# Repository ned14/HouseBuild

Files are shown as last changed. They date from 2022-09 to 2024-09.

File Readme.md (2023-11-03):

Planning application documents can be found at:

http://planning.corkcoco.ie/PlanningDocumentDisplay/documents/18a-224853

Current VR design can be explored using a web browser at:

https://twinmotion.unrealengine.com/presentation/2OuDxP4Q6LUYExYa
Password: jeuCFyiGwG (model was last updated Oct 11 2022)

Current floor plans:

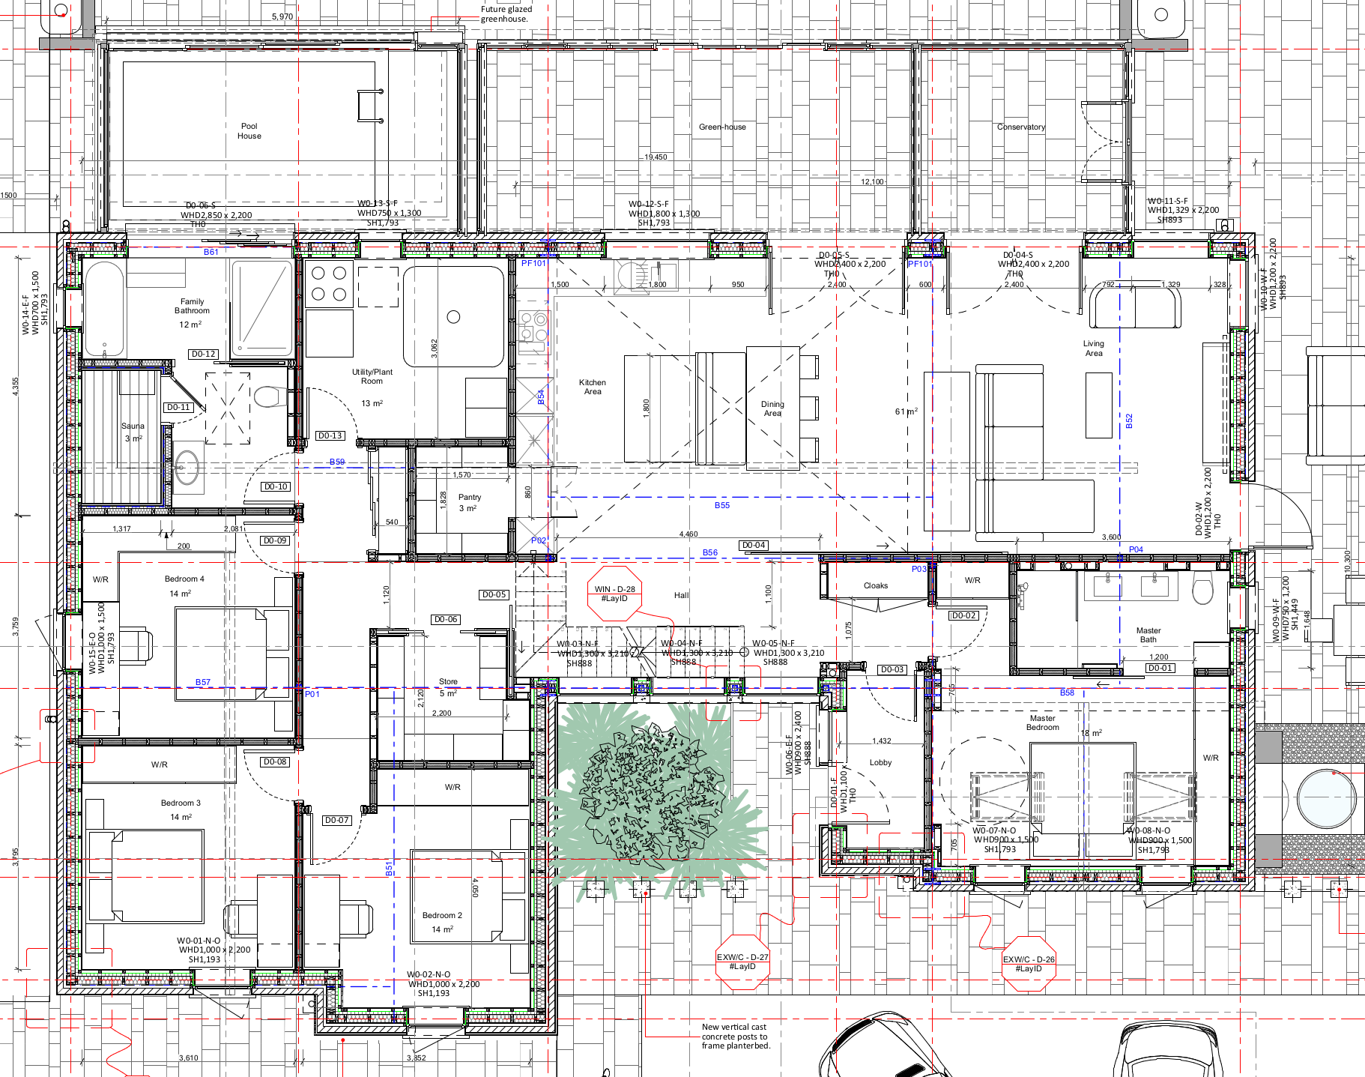
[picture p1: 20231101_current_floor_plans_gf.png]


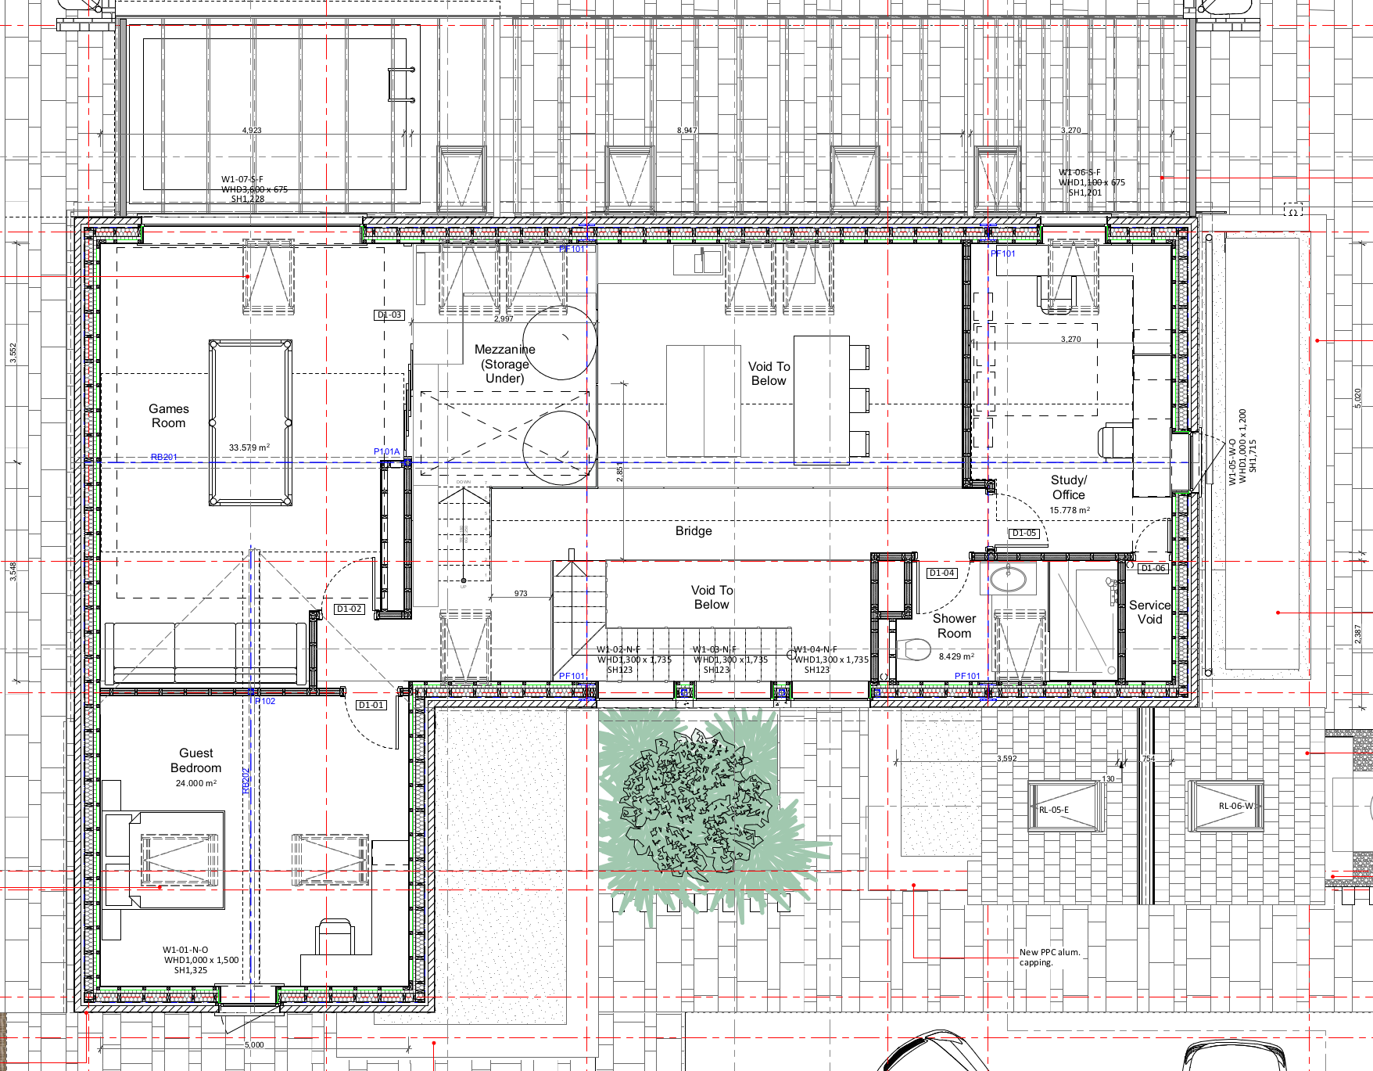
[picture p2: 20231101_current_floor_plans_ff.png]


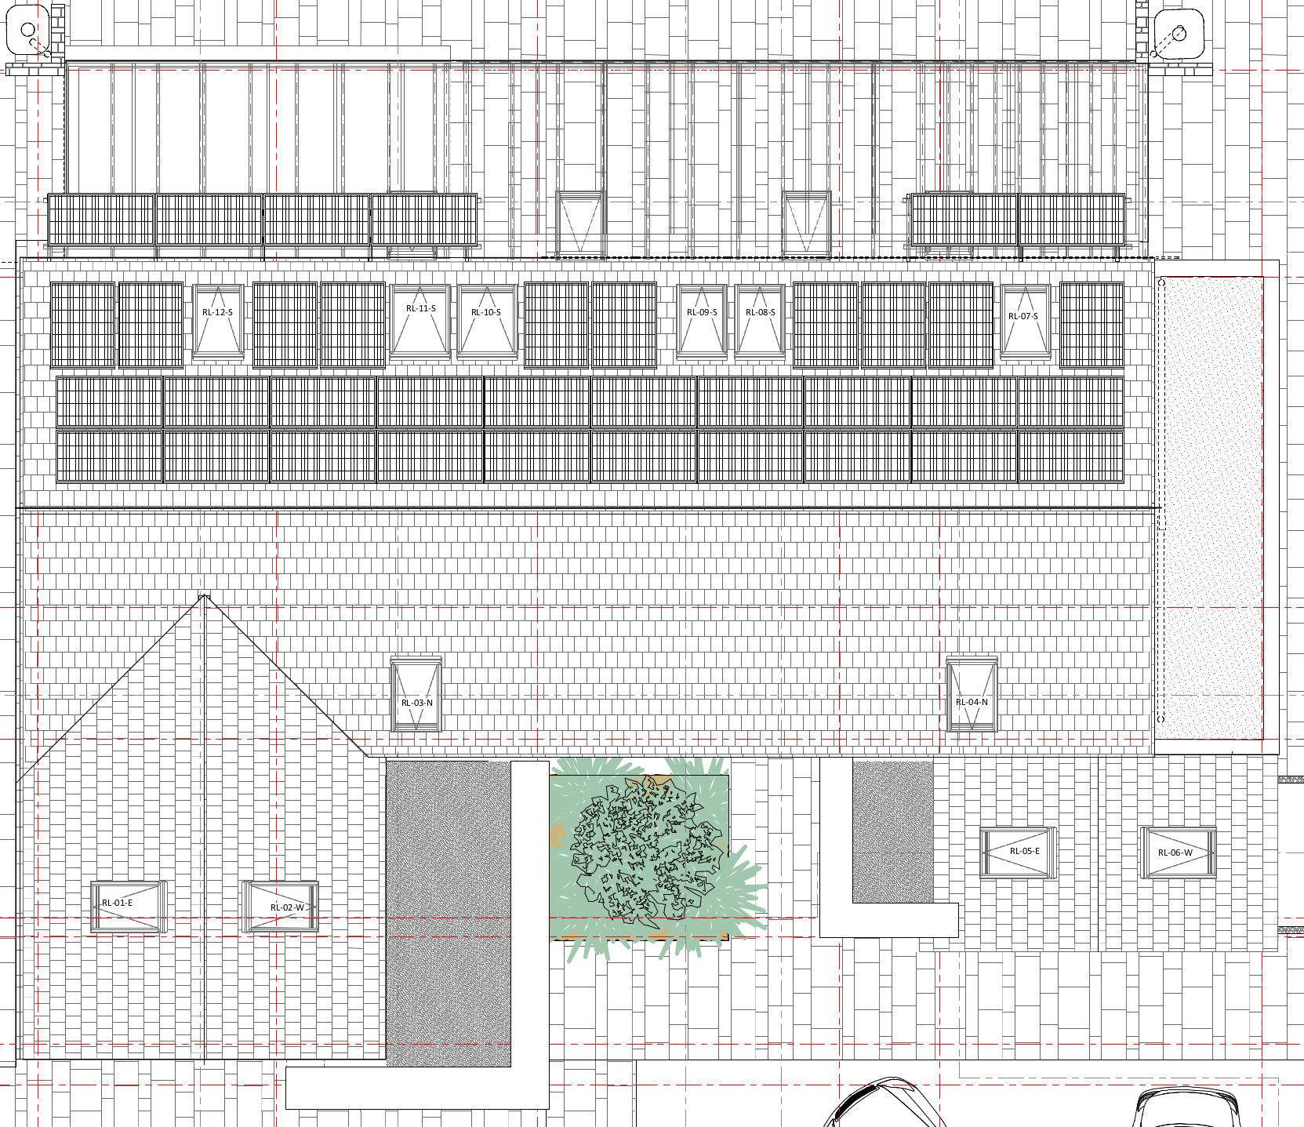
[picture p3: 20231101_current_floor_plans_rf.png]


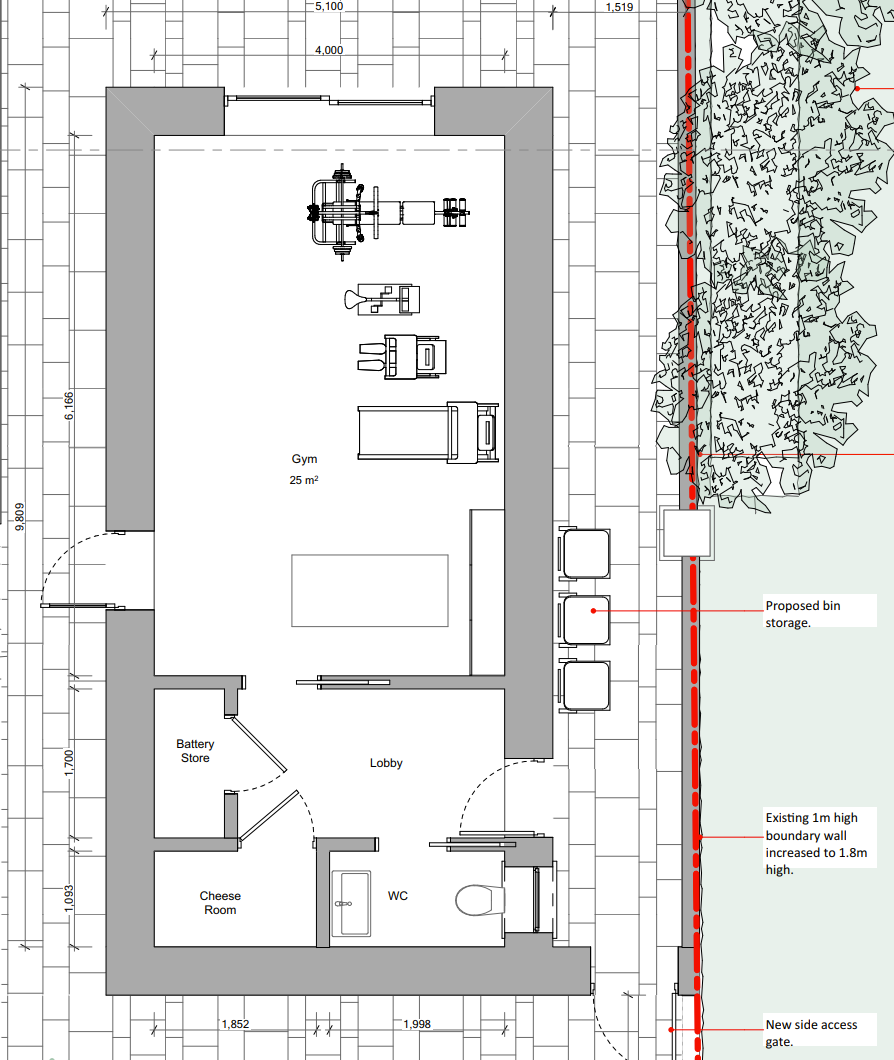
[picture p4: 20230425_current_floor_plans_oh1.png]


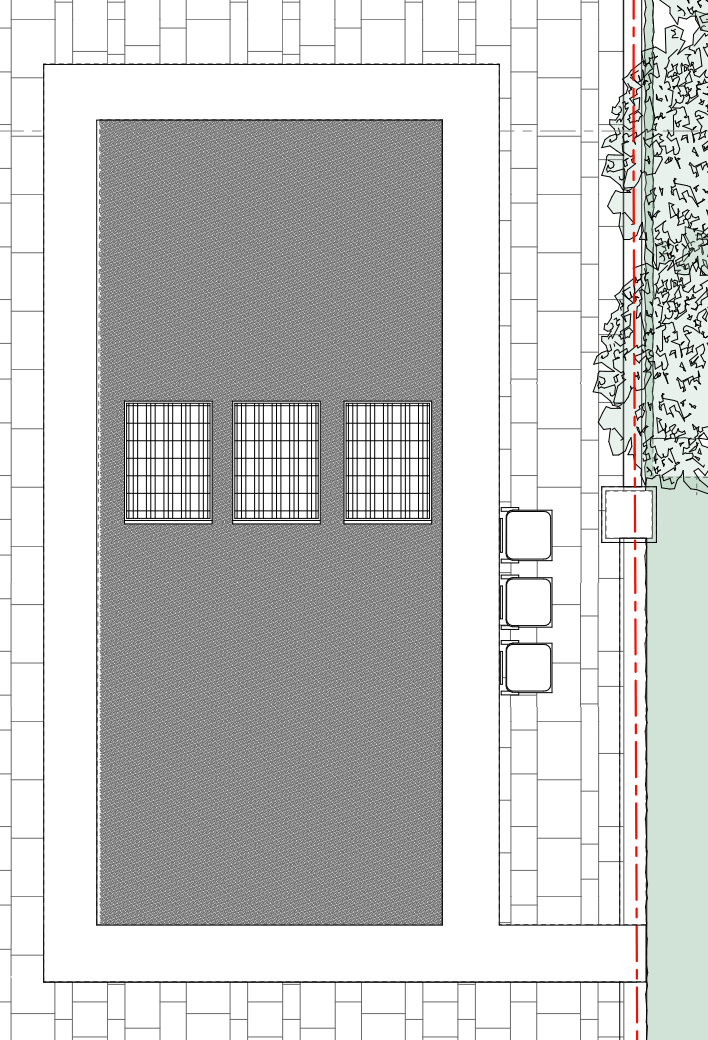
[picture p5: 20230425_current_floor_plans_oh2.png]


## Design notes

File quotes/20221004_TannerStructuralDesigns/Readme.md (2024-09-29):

 Quote is for €10,811.70 inc VAT which includes five site visits.

 PSDP role is further €1,322.25 inc VAT. Each site visit costs €430.50 inc VAT.

 Due to change from builder-led to direct labour, €500 mortgage release fee is replaced with €950 ex VAT fee.

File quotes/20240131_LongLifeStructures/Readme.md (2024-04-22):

# Quote

Main house: €375,382 inc VAT to first fix. This is €1,294 inc VAT per sqm.
    - Timber frame _excluding insulation_ is €229,137 inc VAT. This is €769 inc VAT per sqm.
    - Air tightness and exterior insulation is €63,002 inc VAT.
    - Foundations is €64,322 inc VAT for the house, €18,921 inc VAT for the greenhouse minus pool,
    €20,541 inc VAT for the pool part alone (ouch!).

Outhouse: not quoted

# Includes:

- Main house to first fix.
- All needed _exterior_ insulation.
- Interior partition studs, but not the insulation within them.
- Groundworks (except clearance, hardcore compacted and level by client)
- Floors: 0.10; Walls: 0.134; Roof (sloped): 0.15; Roof (flat): 0.09. Floor is typical KORE insulated slab, 0.10.
- **Guaranteed air tightness < 0.6 ACH to meet passive spec**

# Excludes:

- Structural Engineering (+10k cost)
- Prepatatory groundworks (hard core and services poke up) (+20k cost)
- Roof slates and flat roof (EPDM) (+29k cost)
- Plasterboard (+53k cost)
- Insulation inside internal walls
- External windows and doors (+50k cost)
- Excludes installing roof windows
- Wiring (+10k cost)
- Plumbing (+4k cost)
- External block leaf (plastered) (+53k cost assuming 333 m2 of exterior wall at €160 per sqm plastered)
- External footpaths (+26k cost)
- Glass Ballustarding (+16k cost)
- Stairs (+5k cost)
- Internal doors (+12k cost including skirting and window sills)
- Rubbish removal
- Site costs such as scaffolding, welfare cabin for workers, waste disposal etc.

That is €288k of cost remaining, so total to reach Builder's Finish would be €656k.

If I wanted to add sheep's wool to the inner cavity of the sloped roof to reduce its u-value to 0.13, it might cost:

- Sloped roof area: 9.5 + 11.0 + 21.7 + 21.7 + 54.0 + 43.6 = 161.5 m2
- Assuming 400 centres, reduce by 12% = 144 m2 of insulation needed
- https://www.ecologicalbuildingsystems.com/product/cosywool#product-overview says €7.55 ex VAT per m2, 22 kg/m3, R = 0.039
- So approx +€1,250 inc VAT to add sheep's wool for sloped roof

- Fireproof, denser alternatives:
    - €8.85-€10.24 inc VAT per m2, 35 kg/m3 50 mm https://www.goodwins.ie/products/rockwool-sound-slab-50mm-1-2x400mm-5-76m2-1252120.html. €1,274 inc VAT, almost the same but 59% denser and fireproof. R I think might be 0.035?

For internal wall insulation, which needs more density than anything else:

- €20.23 inc VAT per m2, 37 kg/m3 100 mm https://www.ecologicalbuildingsystems.com/product/thermo-hemp-combi-jute
- €16.82-€19.44 inc VAT per m2, 35 kg/m3 100 mm https://www.goodwins.ie/products/rockwool-sound-slab-100mm-1-2x400mm-2-88m2-1252127.html
- €16.57-€18.75 inc VAT per m2, 35 kg/m3 100 mm https://www.goodwins.ie/products/rockwool-sound-slab-100mm-1-2x600mm-4-32m2-1252128.html
- €15.27 inc VAT per m2, 22 kg/m3 100 mm Rockwool Rollbatt
- €16.84 inc VAT per m2, 12 kg/m3 100 mm Isover Acoustic roll

- Rockwool Flexi (predecessor to Sound Slab) is £14.58 inc VAT per m2 in England, which seems similar to Irish prices.
- Rockwool RWA45 is €23.60 per m2 in Ireland, yet only £8.58 inc VAT in England. It is 45 kg/m3. https://buildersinsulation.co.uk/products/100mm---rockwool-rwa45-acoustic-sound-insulation-slab---2.88m2-pack.html
- Rockwool RW3 is £13.54 inc VAT in England. It is 60 kg/m3.

Just to make a person really wince:

- £27.43 https://www.muffle.co.uk/rockwool-rwa45-acoustic-slab-insulation-100mm-2-88m2-pack-of-4.html
- €68.25 https://ie.muffleacoustics.com/rockwool-rwa45-acoustic-slab-insulation-100mm-2-88m2-pack-of-4.html

# Payment terms:

- €25k incl VAT deposit.
- €83k for the foundations completed (minus pool).
- 40%: Prepayment of offsite manufacture (€92k)
- 40%: Prepayment of install (€92k)
- Balance: Engineering sign for frame (€45k)
- €56k for the airtightness.

€230k needs to go out in near future.

# Other notes:
- The split stud EcoTech Homes quote was for €472,108 inc VAT to first fix. Differences to this quote:

    - Walls: 0.13; Roof (sloped): 0.16; Roof (flat): 0.11

    - Includes roof slates and flat roof EPDM (29k)
    - Includes more of the groundworks (maybe worth 18k)
    - Includes all plasterboard (maybe €53k though that includes labour)
    - Includes installing roof windows
    - Includes insulation for internal walls (5k?).

    Taking those off, that quote would reduce to €367k, literally the same as the split stud EcoTech quote on a like for like basis.

- The single stud EcoTech Homes quote was for €361,297 inc VAT to first fix. Differences to this quote:

    - Walls: 0.16; Roof (sloped): 0.16; Roof (flat): 0.11.

    - Includes roof slates and flat roof EPDM (29k)
    - Includes more of the groundworks (maybe worth 18k)
    - Includes all plasterboard (maybe €53k though that includes labour)
    - Includes installing roof windows
    - Includes insulation for internal walls (5k?).

    Taking those off, that quote would reduce to €256k. So the above quote is 111k more than the single stud EcoTech quote on a like for like basis.

- Closest competing quote for a similar spec is TimberFrameIreland. This is from last year for a 300 mm split stud:

    Main house: €218,328 inc VAT to first fix (€92,620 + €38,030 "The Eco Package" which is the 300 mm split stud + €2,690 + €6,740 + €860 + €51,420). This is €732 inc VAT per sqm.

    - Excludes air tightness taping (14k probably)
    - Excludes air blower test
    - **Question:** Is roof truss and flat roof insulation included by TimberFrameIreland? If not, potentially 20k there.

    - Walls have 0.11 u-value instead of 0.13. Roof (sloped) has 0.11 u-value instead of 0.13.

    Assuming same cost of air tightness and insulation minus walls (so maybe +35k), that would be 253k inc VAT. The above quote is 71.9% more money for 18% worse u-values.

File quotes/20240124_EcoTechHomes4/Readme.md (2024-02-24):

# Quote

Main house: €472,108 inc VAT to first fix. This is €1,584 inc VAT per sqm.

Outhouse: not quoted

# Includes:

- Main house to first fix.
- Roof slates
- Flat roof (EPDM), insulation partially fitted.
- Plasterboard, **but not fitted**
- Groundworks (except clearance, hardcore compacted and level by client)
- Floors: 0.10; Walls: 0.13; Roof (sloped, excludes insulated plasterboard): 0.16; Roof (flat): 0.11. Floor is typical KORE insulated slab.
- **Guaranteed air tightness < 0.6 ACH to meet passive spec**

# Excludes:

- **Insulated floor for greenhouse**
- Structural Engineering (+10k cost)
- External windows and doors (+50k cost)
- Wiring (+10k cost)
- Plumbing (+4k cost)
- External block leaf (plastered) (+53k cost assuming 333 m2 of exterior wall at €160 per sqm plastered)
- External footpaths (+26k cost)
- Glass Ballustarding (+16k cost)
- Stairs (+5k cost)
- Internal doors (+12k cost including skirting and window sills)
- Rubbish removal
- Site costs such as scaffolding, welfare cabin for workers, waste disposal etc.

# Payment terms:

-  6.5%: Initial deposit
- 18.0%: Prepayment of foundations
- 16.5%: Prepayment of offsite manufacture
- 42.0%: Prepayment of install
- 14.0%: Prepayment of roof slates
-  3.0%: After completion

# Other notes:
- This differs from the earlier quote as it is for a 300 mm split stud with posi-joists, rather than 220 mm with normal joists. The price for the earlier spec was €361,297 inc VAT. This, obviously enough, is €110,811 more.
- Estimated cost to Builder's Finish: €684k inc VAT.
- Closest competing quote is TimberFrameIreland. This is from last year, but for the same 300 mm split stud:

    Main house: €218,328 inc VAT to first fix (€92,620 + €38,030 "The Eco Package" which is the 300 mm split stud + €2,690 + €6,740 + €860 + €51,420). This is €732 inc VAT per sqm.

    - Excludes roof slates and flat roof EPDM (29k)
    - Excludes more of the groundworks (maybe worth 18k)
    - Excludes internal wall insulation
    - Excludes all plasterboard (maybe €53k though that includes labour)
    - Excludes installing roof windows
    - Excludes air blower test
    - **Question:** Is roof truss and flat roof insulation included?

    - Walls have 0.11 u-value instead of 0.13. Roof (sloped) has 0.11 u-value (includes plasterboard) instead of 0.16 (excludes plasterboard).

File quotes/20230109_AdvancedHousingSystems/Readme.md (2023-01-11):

# Quote

Main house: €643,699 inc VAT to second fix (€545,040 superstructure; €98,659 substructure). This is €2,083 inc VAT per sqm.

Outhouse: not quoted

# Includes:

- Main house to second fix.
- Insulated floor for greenhouse
- **Structural Engineering**
- **M&E engineering**
- Floors: 0.10; Walls: 0.10; Roof: 0.10.
- Internal walls: 100mm quilt wool insulation.
- **Guaranteed air tightness < 0.6 ACH to meet passive spec**

# Excludes:

- Everything between second fix and builder's finish (e.g. wiring, plumbing, door frames, skirting boards)
    - +10k cost electrical, +4k cost plumbing
- External block leaf (plastered) (+53k cost assuming 333 m2 of exterior wall at €160 per sqm plastered)
- External footpaths (+26k cost)
- Roof slates (+25k cost)
- Glass Ballustarding (+16k cost)
- Stairs (+5k cost)
- Internal doors (+12k cost including skirting and window sills)
- Rubbish removal
- Site costs such as scaffolding, welfare cabin for workers, waste disposal etc.

# Payment terms:

- 12%: Initial deposit
- 12%: Design completion
- 22%: Prepayment of offsite manufacture
- 9%: Prepayment of windows and doors
- 20%: Offsite manufacture completed
- 10%: Arrival of team onsite
- 4%: Delivery of windows and doors
- 8%: Completion of superstructure ground floor
- 3%: Completion of superstructure build

# Other notes:

- The cash flow crunch is going to be particularly problematic here, because the bank's mortgage drawdown stages don't map onto their stages. I reckon I would need to front about half the total build cost which would need to be completed before the bank would let me drawdown. That is a problem.
- Once accounting for structural and M&E engineering, this is a touch (13k!) cheaper than the Ecotech quote.
    - I filled in the items which the Ecotech quote includes, but we'd need to supply with this contractor, from the Quantity surveyor's estimates. It thinks those items would sum to €151k. On that basis, this quote ought to be €795k.
- The spec of this house is way higher than the Ecotech quote. Vastly superior u-values for one, I suspect build quality would be better too, so the +21% cost is likely competitive for the spec delivered. However €138k is an awful lot of money which can be used to buy other stuff instead.

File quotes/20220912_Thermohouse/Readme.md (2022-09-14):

# Quote

Main house: €226,213 inc VAT to passive spec wall insulation < 0.15 u-value. This is €732 inc VAT per sqm.

Outhouse: €40k inc VAT (note that they omitted the insulated floor)

# Includes:

- Substructure and **Outer** Superstructure, no Windows nor Doors, no Foundations, no Ground Floor, no Services.
- First floor.

# Excludes:

- Structural Engineering
- Excavation and backfilling
- Foundations
- **Ground floor**
- Window cills
- Stairs
- **Most of the internal walls**
- Roof tiles, fascia and soffet
- **Outer leaf**
- Site costs such as scaffolding, welfare cabin for workers, waste disposal etc.
- **Any form of air tightness testing or guarantees related to air leakage**
- The steel frame for the glazing at the front of the house.

# Payment terms:

- 20% deposit
- Stage payments at ground floor, floor panels, first floor, steel and finally the roof panels

# Other notes:

- If combined with outer block leaf, they claim it falls under 'standard construction' and I suppose given it's then similar to insulated block on flat it probably does tick that box.
- To reach passive air tightness with ICF one generally must spray all the inside of the building enveloper with a rubberised layer to seal all the tiny gaps. As with any new building, foundations will shift over time and tears can appear in that rubberised layer, requiring a second spray a decade in or so.
- Obviously all that concrete, polystyrene and steel is absolutely hideous for the embodied CO2, though not much between this and the average NZEB spec Irish new build to be honest.

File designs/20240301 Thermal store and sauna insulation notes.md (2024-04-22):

## U-values

- 0.639 30mm thick  30mm Kingspan Sauna Satu
- 0.616 45mm thick  15mm plasterboard + 30mm Kingspan Sauna Satu
- 0.592 50mm thick  mineral wool
- 0.341 75mm thick  15mm plasterboard + 30mm Kingspan Sauna Satu + 30mm Kingspan Sauna Satu
- 0.283 68mm thick  37.5mm Kingspan K118 insulated plasterboard  + 30mm Kingspan Sauna Satu
- 0.238 80mm thick  50mm Kingspan K108 phenolic board + 30mm Kingspan Sauna Satu
- 0.186 103mm thick 72.5mm Kingspam K118 insulated plasterboard  + 30mm Kingspan Sauna Satu
- 0.181 105mm thick 75mm Kingspan K108 phenolic board + 30mm Kingspan Sauna Satu

Apparently Kingspan phenolic board is happy with continuous 120 C, and they originally make it by baking it at over 200 C. I'm not entirely sure why they use PIR for saunas not phenolic, as supposedly phenolic is moisture safe as well.

Thermal store is 1.7 x 1.7 x 2.91 = 19.8 m2 sides + 5.8 m2 top bottom = 25.5 m2 all surfaces.

BUT one side is exterior wall at 0.15 u-value, so 5 m2 get 0.11 u-value, 20.5 m2 gets rest. So 20% gets 0.15 u-value, 80% gets rest.

If inside is 85 C and outside is 20 C then 65 K difference => 1332.5 m2K for interior, 325 m2K for exterior.

If inside is 55 C and outside is 20 C then 35 K difference => 717.5 m2K for interior, 175 m2K for exterior.

In reality, bottom will not be as warm at top, so leakage will be better than these:

### Winter:

- 0.639 u-value => 851 + 36 = 887 watts leakage worst case
- 0.283 u-value => 377 + 36 = 413 watts leakage worst case
- 0.181 u-value => 241 + 36 = 277 watts leakage worst case

### Summer:

- 0.639 u-value => 458 + 19 = 477 watts leakage worst case
- 0.283 u-value => 203 + 19 = 222 watts leakage worst case
- 0.181 u-value => 130 + 19 = 149 watts leakage worst case

I know from https://core.ac.uk/download/pdf/13724924.pdf that for a 1.7 m tall tank insulated with 50mm of mineral wool, heat stratification will result in a max 14 C temp difference. If there is any churn at all, more like 11 C. That is approximately 13-14 cm per degree of temp difference.

For a 2.8m tall tank, the temp difference could be 20 - 22 C, for 50 mm of mineral wool. 50 mm of mineral wool has 0.592 u-value.

Let's assume better insulation has a linear effect on stratification. Temp delta to outside would
be average of top and bottom temps, so if there is a 21 C top-bottom difference, a 65 K delta
becomes 65 - (21 / 2) = 54.5.

### Winter:

- 0.639 u-value =>  21 C temp diff => 83.8% = 743 watts after stratification
- 0.283 u-value =>  10 C temp diff => 92.3% = 381 watts after stratification
- 0.181 u-value => 6.4 C temp diff => 95% = 263 watts after stratification

### Summer:

As only top quarter heated, assume tank is one third normal height and thus loses one
third of worst case.

- 0.639 u-value => 159 watts
- 0.283 u-value => 74 watts
- 0.181 u-value => 50 watts

## Wood

Alder and Aspen are the only two woods one should use in a sauna. Not cedar.

Spruce is cheaper, but can emit resin which will burn you and is sticky.

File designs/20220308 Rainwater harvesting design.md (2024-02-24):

# Rainwater harvesting design

(These notes were reconstituted from many emails around that time)

Model soakaway crate used is 1000 x 1000 x 400 mm deep and requires 500 mm of soil above it.

- https://www.drainagesuperstore.co.uk/product/aquacrate-stormwater-soakaway-and-attenuation-crate-20-tonne-25-per-m3.html
- https://www.drainagesuperstore.co.uk/user-guides-brochures/aqua-crate-400-data-sheet.html

Top of the lower reed bed tray to be 74.25. Top of the 0.4m deep soakaway to be 74.19, with a 6 cm fall between them. Each reed bed tray is 0.2m fall.

Footpath north of house is 74.60. Channel drain south of footpath 74.50 (slope 1% from house footpath). Footpath east of outhouse is 74.60. Top of first reed bed tray is 74.47 (slope 0.5% from channel drain next to outhouse). Top of second reed bed tray is 74.25 (0.22m drop). Top of underground storage tank is 74.24.

For underground storage to overflow into stormwater mains, top of stormwater drain has to be no higher than 73.99 (1% slope over 15 metres). Footpath is 74.36, and min thickness according to regs is 225 mm. Assuming 250 mm, top of stormwater drain will be no higher than 74.11 and as a 110mm diameter pipe, its bottom would be 74.00.

---

(These are written now, in Jan 2024)

I can't explain, looking at it now, why I thought a 0.2m fall is needed _per tray_. As far as I can tell now, It is a _once off_ 0.2m fall into the 0.8m deep tray, because the inlet pipe comes in below the top of the tray. The Kingspan trays take a 110 mm inlet pipe, the Herr trays seem to take a 50 mm inlet pipe. After your once off 0.2m drop from the top, the trays can all be equal height as static pressure will ensure each tray gets the same height of water -- indeed, they could be connected by a bottom pipe for water level equalisation, and the outlet water drawn off the top.

That might explain some of the more confusing parts of the above where I did the measurement of the outlet from the top of the second tray. I must have also been thinking in at top, between trays at bottom, out at top.

The Kingspan tray is 2.5m long, 0.8m wide and 0.8m deep. Not sure what the dimensions of the Herr tray is.

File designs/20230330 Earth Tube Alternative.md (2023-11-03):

Given that quotes for the Rehau Awadukt Thermo delivered to Ireland are
coming in over €7k ex VAT, what alternatives are there?

# Option 1: Water pipes

The Rehau pipes are just very high quality polypropylene 200 mm mains
water pipes with a specially sprayed inner of silver oxide. One
could just source bog standard 200 mm mains water pipes instead.
https://www.mcmahons.ie/200mm-pvc-watermain-pipe-class-c-x-6m
lists 200 mm 10 bar capable PVC watermains pipes 6m length for
€80.89 ex VAT each. This seems suspiciously cheap? They also have a
250mm diameter edition. These probably refer to outside diameter,
not DN diameter which is the inside.

225 mm 6m length PVC sewer pipes cost €137 ex VAT each. 

You can buy from https://www.amazon.de/Stainless-Steel-Suction-Tower-Filters/dp/B07DHQHV6H?ref_=ast_sto_dp
the air inlet tower with five spare filters for under €600 inc VAT
delivered for DN200, or https://www.amazon.de/Stainless-Steel-Suction-Tower-Filters/dp/B07DHQYPCH?ref_=ast_sto_dp
for DN250 for under €700 inc VAT delivered.

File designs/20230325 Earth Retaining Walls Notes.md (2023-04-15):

Worst case weight loading is:

     - Blocks are 1.4m long 0.68 wide 0.7 tall. Exactly 0.6666667 m<sup>3</sup>.
     - 7.5 blocks long three blocks high = 10.5m x 0.68 = 7.14 m<sup>2</sup> of area
     - 7.5 blocks long three blocks high = 31,500 kg

Therefore worst case weight loading is 4,412 kg per m<sup>2</sup>.

Safe bearing capacity of soils:

    - Medium clay: 25,000 kg per m<sup>2</sup>.
    - Packed fine sand: 15,000 kg per m<sup>2</sup>.
    - Loose fine sand: 10,000 kg per m<sup>2</sup>.
    - Soft clay: 10,000 kg per m<sup>2</sup>.
    - Very soft clay: 5,000 kg per m<sup>2</sup>.

Should be no problem there.

Normal solid concrete blocks have a density of 2,000 kg/m<sup>3</sup>.
These have 2,100 kg/m<sup>3</sup>.

Therefore footing probably ought to be at least 150 mm deep and 1.0m wide.

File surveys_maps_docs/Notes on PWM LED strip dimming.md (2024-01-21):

The house exterior and site will be mainly illuminated by RGBWW LED strips which each have a five pin connector:

1. Common anode +24v
2. Red
3. Green
4. Blue
5. Warm white (3200K)

## Exterior

The exterior LED strips have already been purchased:

- 50x 5m IP67 Tube Waterproof 24v SMD 5050, 60 LEDs/metre
    - To be used edges of house fascia, edges of site.
    - Listing claimed max 12w/metre and 350-450 mcd/LED. Likely 20% worse.
    - Probably max 72w 3.0 amp on the anode.
    
- 4x 5m 1P67 Tube Waterproof 24v **double row** SMD 5050, 120 LEDs/metre
    - To be used where more brightness is needed e.g. western wall outhouse passage, inside of shipping container
    - Listing claimed 16w/metre and 18-20 lumen/LED. Empirical testing found 20w/metre (listing was 20% under this), and 2,200 lumen/metre from subjective sight seems generous.
    - Max 100w 4.2 amp on the anode, may be able to get more brightness if both ends are wired in as the common anode will limit max current. Strictly speaking only the +24v common anode needs wiring in at both ends.

## Interior

- 5x 5m 3500K CRI95 LED strip 11w/metre.

    - 3x for roof of living area above TV.
    - 1x for end of hallway.
    - 1x for back of games room.

All likely using the recessed LED channels below.

- 1x 5m 4000K CRI95 waterproof LED strip 28.8w/metre.

    - Upstairs bathroom where we needed an ultra bright
strip to uplight. Had wanted 3500K but couldn't get
that in waterproof. Couldn't get 3000K either, only 2800K,
so ended up going for 4000K which is disappointing but water
under the bridge now.

- 1x 5m 3000K CRI95 ultra bright LED strip 38.4w/metre.

    - Top of stairs around grandfather clock. This is beyond
ultra bright, more like insanely bright. Idea here is to uplight
from below so it will be reflecting back down.

- 1x 5m 3000K RA90 RGBWW COB LED strip.

    - Sauna.

- 2x 5m 3700K COB LED strip 15w/metre.

    - Additional lighting around both ground floor showers.
Not waterproof, but it'll be inside recessed channels and
it's COB so it should be fine.

- 1x 5m 4000K RA95 COB LED strip 10w/metre.

    - Ground floor bathroom mirrors MISSING STRIP FOR ONE
MAYBE TWO.

- 24x 3000K CRI90 MR16 bulb 120 degree 7w.

    - Accidentally got ten too many. Anywhere needing a
wide cosy throw where people are standing e.g. hallways,
utility, bathrooms.

    - These were very cheap (under €1 delivered), and appear to
have no heatsink at all. They get hot quickly at full power,
and will need PWM dimming to get much lifespan from them. They are
marked 'Gatetop' but that's the Aliexpress shop front name, most
of the MR16 bulbs on Aliexpress are likely from the same manufacturer.

- 8x 3000K CRI90 MR16 bulb 38 degree 7w.

    - Mainly bedrooms, the warmest colour we use.

    - These were very cheap (under €1 delivered), and appear to
have no heatsink at all. They get hot quickly at full power,
and will need PWM dimming to get much lifespan from them. They are
marked 'Gatetop' but that's the Aliexpress shop front name, most
of the MR16 bulbs on Aliexpress are likely from the same manufacturer.

- 15x 3500K CRI90 MR16 bulb 40 degree 8w.

    - Living spaces where high CRI matters.

    - These are called "expensive Satco" below. They were about US$12
each. They dim very smoothly over a large range, have clearly superior
heatsinking, and their power regulator doesn't care about input voltage
which suggests a fully switched power converter. These are clearly the
best bulbs I bought on all measured metrics, but at 15x the cost of
the very cheap Aliexpress ones I'd wonder if there is cost benefit.

- 12x 3500K CRI80 MR16 bulb 40 degree 6w.

    - Living spaces where lower CRI can be tolerated.

    - These are called "cheap Satco" below. They were about US$9
each, three quarters the price of the expensive Satco. They have at least
some heatsinking compared to the very cheap Chinese bulbs resulting
in temperatures a few degrees lower, but otherwise seem very similar
i.e. they get hot fast, and may even have an inferior driver IC to those
very cheap bulbs (see below).

- 16x 4000K CRI90 MR16 bulb 38 degree 7w.

    - Anywhere needing focus and concentration i.e. kitchen
countertops, home office.

    - These were very cheap (under €1 delivered), and appear to
have no heatsink at all. They get hot quickly at full power,
and will need PWM dimming to get much lifespan from them. They are
marked 'Gatetop' but that's the Aliexpress shop front name, most
of the MR16 bulbs on Aliexpress are likely from the same manufacturer.

- 24x fixed 3cm recessed downlight fixtures.

    - Hallways, kitchen countertops.

- 36x tiltable 3cm recessed downlight fixtures.

    - Everywhere else.

- 27x 0.5m recessed aluminium LED strip channel for 8mm wide tape.

- 30x 0.5m recessed aluminium LED strip channel for 12mm wide tape.

- 10x 0.5m double sided aluminium LED strip coving.

- 10x 0.5m brushed black skirting channel for LED strip.

- 10x 0.5m brushed rose gold skirting channel for LED strip.

- 10x 6 amp two pole DC circuit breakers.

- 10x 6 amp one pole DC circuit breakers.

- 28x 12 AWG mini car fuse leads.

- 25x 8 kHz DC PWM wall dimmer switches.

    - Verified with oscilloscope these genuinely do run an 8 kHz
PWM. They're actually configurable between 500 Hz, 1 kHz, 2 kHz,
4 kHz and 8 kHz. This turns out to be super useful when paired
with the MR16 bulbs, which expect clipped AC to tell them when
to dim.

- 2x 4 Khz DC PWM wall dimmer switches.

    - Bought in case the 8 kHz switches didn't work out as samples.
Turns out the 8 kHz switches work great.

- 4x touchpanel RGBW wall dimmer switches.

    - Only need one, but bought spares as they were very cheap
and I don't trust the touch interface at all to be reliable.

## PWM dimming

### MOSFET choices

For some reason, the 5v "logic level" IRLxxx MOSFETs don't seem to come on convenient breakout breadboards, only the 10v IRFxxx MOSFETs do (note the 'L' vs 'F' difference). This is unfortunate, however what I really would want is 3.3v MOSFETs so I can skip the logic level shifter which is added cost and wiring (that said, what max frequency an affordable 3.3v MOSFET could switch at I don't know).

The two choices of MOSFET on convenient breakout boards and which are cheap are chinese clones of the IRF520N and IRF540N, both 10v saturating devices. Both allow a reasonable current for a 5v saturation, albeit considerably less than the maximum current they are capable of. I guess this is why "they'll do" for most makers.

I have a bunch of single channel IRF520N boards from my initial round of purchasing in 2021, and one of those powers the experimental LED strip cover lighting in the living room of my rented house. It works pretty well, albeit the MOSFET does run hot i.e. wastes energy.

To see if I could improve on this, I bought 10x cheap four channel IRF540N MOSFET boards to test if that single integrated board would be feasible and save me hassle wiring up individual MOSFETs. These are optically isolated apart from ground, and have a LED wired inline to the MOSFET input which roughly lops half a volt off the signal voltage. They present a common anode, and switch the cathode only which is perfect for the LED strips. The optocoupler chip (PS2801-4) limits the output voltage to 9 - 80v, as it is powered by the output voltage.

Assuming that the chinese clone MOSFETs have these characteristics:

<table>
<thead><th><th>IRF520N<th>IRF540N
<tbody>
<td align="right">R<sub>DS</sub><td>0.20<td>0.052
<td align="right">R<sub>thJA</sub><td>62<td>62
<td align="right">Max I<sub>D</sub> for<br>V<sub>GS</sub> @ 4.5v<td>2.5 A<td>20 A
<td align="right">Max I<sub>D</sub> for<br>V<sub>GS</sub> @ 5.0v<td>4 A<td>32 A
<td align="right">Max I<sub>D</sub> for<br>V<sub>GS</sub> @ 10v<td>9.7 A<td>33 A
</tbody>
</table>

Heating in watts = Current ^ 2 * R<sub>DS</sub>

Resulting temperature increase over ambient = Heating watts * R<sub>thJA</sub>

Where R<sub>DS</sub> is for a control voltage of 10v and the MOSFET's temperature is 20 C:

<table>
<thead><th>Current<th>IRF520N watts<th>IRF520N temp<th>IRF540N watts<th>IRF540N temp
<tbody>
<td>0.63 A<td>0.08 W<td>+5.0 C<td>0.02 W<td>+1.3 C
<td>1.00 A<td>0.20 W<td>+12 C<td>0.05 W<td>+3.2 C
<td>2.00 A<td>0.80 W<td>+50 C<td>0.2 W<td>+13 C
<td>2.50 A<td>1.25 W<td>+78 C<br>(needs cooling)<td>0.33 W<td>+20 C
<td>4.00 A<td>3.20 W<td>+198 C<br>(needs cooling)<td>0.82 W<td>+52 C
</tbody>
</table>

One would multiply watts and temp heating by 1.5 if the temperature were 100 C, so clearly the IRF520N runs away with waste heat past 2.0 A or so. One probably ought to also increase the heating to account for a control voltage of 4.5v vs 10v.

I have a IRF520N on the living room LED strip which I think draws about 2.2 A, and it gets really quite hot even with its heatsink. With hindsight it was the wrong choice of MOSFET for such a high current, but at the time I didn't know any better.

In any case, I reckon the four channel IRF540N boards should waste no more than 0.4 W of heat from the four MOSFETs if the LED strip is fully on for the 120 LEDs/metre strips, and 0.16 W for the 60 LEDs/metre strips. Given that each ESP32 board and its associated 60v to 24v converter will waste single digit watts, I don't think the losses from the MOSFETs will matter (and they won't need heatsinking either).

### MOSFET control option 1: Use direct PWM

The industrial ESP32 boards can PWM dim up to twelve channels, so theoretically up to three 5m LED strips can be controlled per board. In practice, most use cases will have an ESP32 board per two LED strips, as the other GPIO will be used for I2C sensors etc.

Probably a 14,648Hz PWM will be used, which gives 4,096 steps per RGBW channel. You need to make sure when introducing logic level shifters or optoisolaters etc that they are capable of switching at at least that frequency. Any bog standard FET based level shifter should be capable of 100 Khz, if you need more then a buffered level shifter such as the TXS0108E should be good up for 2 - 60 Mhz which should be enough to level shift even a SPI connection.

As inferred here, you will need a level shifter with this option, because the FET needs a 5v control signal to saturate. Whilst inexpensive, the level shifter boards each need soldering and wiring in with two sets of power and control signals and this is hassle. If one has other 5v peripherals, this might be okay, but to be honest it's rare I'd choose a peripheral without 3.3v control support, even if it a 5v powered device.

### MOSFET control option 2: Use a PCA9685 LED driver

These cost under €3 inc VAT delivered and provide sixteen i2c controlled PWM channels with 4,096 steps per channel. They can output 5v whilst being controlled by 3.3v, which saves on level shifters. ESPHome treats them as if ESP32 PWM outputs, so integration is seamless and you can of course daisy chain them as they are i2c devices. The only bad thing about them is that they probably still need soldering (though all the Aliexpress photos show them presoldered), and their maximum PWM clock is 1,526Hz which is unfortunately low (flicker).

### MOSFET control option 3: Use a TLC5947 LED driver

These cost under €7 inc VAT delivered and provide twenty-four SPI controlled PWM channels with 4,096 steps per channel. They can output up to 30v at 30mA, and work just fine with 3.3v control. They have a 4Mhz clock, which is surely sufficient, and can be daisy chained on SPI.

In case you're thinking we could have them drive a higher voltage than 5v into the MOSFETs to save heat wastage, yes you can. But we only have available 24v or 5v, and the MOSFETs won't take more than 20v into their input without burning out.

As with all the other options, these also need soldering, but the fact you can run eight LED strips from each board and with good quality dimming is attractive.

### MOSFET control option 4: Use a 24v PWM dimming rotary wall switch

This is the most expensive option, costing €17.20 inc VAT delivered each. Though it also saves on the cost of a wall switch, its single most attractive feature is saving me time. This is actually the one I ended up choosing, despite its expense, as my time is so very limited. I can later upgrade lighting control with ESP32 as needed.

The unit I bought claimed it could work with 12v (the listing claimed 5v) to 24v at up to 6 amps, with 180 watts specified as maximum (that doesn't make sense to me either). It claims to support five output frequencies: (i) 500 Hz (ii) 1000 Hz (iii) 2000 Hz (iv) 4000 Hz (v) 8000 Hz. This will be useful for working with MR16 bulbs, that expect an AC dimming signal. I couldn't tell from the Aliexpress description if they meant dimming levels, or PWM frequency (later I used an oscilloscope to check, and they did mean PWM frequency, these switches do use a 8000 Hz PWM frequency when so configured).

Having received them and cracked one open, they are based on two 60N03 MOSFETs. The MOSFETs can cope with up to 30v and their control signal is TTL, and the datasheet reckons they can push up to 320 watts. There is a TM1651 LED driver control IC, but it is for the eight segment number display only. An unmarked IC appears to do all the real work. A 78L05 voltage regulator takes in 0 - 30v and outputs 5v, its datasheet says it needs a minimum 7.5v to produce 5v. With 5v input it produces 3.5v, which is above TTL so a lot of ICs should still work. All the ICs with identifiers I could see their datasheets all say they're happy at 3.3v, so only the unmarked IC will be the question. I ended up putting it onto my variable voltage power supply, it appears (just about) happy at 5.0v albeit with the numbers display rather dim, but 4.8v is too little and it hangs. The numbers display appears to reach full brightness at around 8v, so I suspect its needs 5v from that voltage regulator for full brightness but is happy down to TTL.

After empirical testing, I have found:

- The very cheap Chinese MR16 bulbs have no issue being put into series, which to be honest was rather the surprise. Each claims 10v for itself minimum, one of the other bulbs takes the balance, it all 'just works'.
- The Satco bulbs don't like being put into series at all. One goes out, the other gets full voltage.

The dimmer switch PWMs the cathode, so you get a series of pulses connecting to ground. Unfortunately the MOSFET boards above are anode switched, with a pull up resistor you can invert the dimming setting, but that's hardly ideal.

I could install special 54v => 12v converters throughout the house and put the Satco bulbs in parallel, however I already have lots of 54v => 24v converters in stock and they're more efficient in any case. It seemed above that the Satco bulbs don't mind 24v input:

- The AMC7105 MR16 driver IC will accept between 4.0v and 40v.
- The iW3662 MR16 driver IC will accept between 10.0v and 24v.
- The MAX16840 MR16 driver IC will accept between 5.6v and 46v.
- The MAX31840 MR16 driver IC will accept between 6.5v and 26v.
- The TPS92560 MR16 driver IC will accept between 6.5v and 42v.

These seem to be the most common MR16 LED driver ICs, and they all accept 24v.

**Unfortunately** from thermal camera testing of the very cheap Chinese MR16 bulbs it would seem the higher the input voltage, the much more heat gets output which means bulb lifetime will be impacted, so using 24v throughout for those is probably unwise. Whatever IC they use it appears to treat 10v as 100% brightness, and it performs a dim down to about 4v -- anything above 10v appears as increased heat dissipation (even 12v), so they might even have a linear regulator in there to save costs. I saw a max temp of 60 C on 10v with it going to 72 C on 12v, it went to 80 C before I pulled the plug on 24v. Unfortunate.

For the cheap Satco, it was a similar story to very cheap Chinese bulbs: more voltage equals more heat, but the heatsinking is slightly better. The 24v bulb went to 90 C within a few minutes, the 12v bulb got to 58 C. Dimming is smooth between 3.6v and 10v, I couldn't see brightness change 10v to 12v.

For the expensive Satco, they are completely idempotent to input voltage. On both 12v and 24v they reach 46 C and stay there. Identical. They turn on quite brightly at 3.6v which is the lowest my variable power supply can go, and have a smooth dim from there right up to 12v which appears to mean 100% for them. In PWM dimming testing these bulbs had by far the widest dimming range, going from just above off smoothly to full brightness. I very much like the colour of the light from the bulbs, they're generally just lovely. I guess you get what you pay for, and the cheap Satco are actually lousy value for money considering they're barely better than the 'Gatetop' Aliexpress bulbs at one tenth their price.

I guess what all this means is I'm going to need a bunch more ~60v DC to 10v DC converters (more likely it'll be 12v). Let's hope the January sales have hefty discounts.

For sizing:

- Very cheap Chinese use ~0.44 amps at 12v. As you drop the voltage below 10v, amps also drops with voltage as they dim. They claim to be a 7w bulb, that clearly is usual Aliexpress 'listing claims 25% over reality' at 5.3w at most.
- Cheap Satco use ~0.56 amps at 12v. As you drop the voltage to 8v they will ramp up amps to 1 amp, after which they dim whilst holding current constant. They claim to be a 6.5w bulb, however they actually consume as much as 8w and run at 6.72w normally. These really are poor bulbs, consuming up to 8w when their box claims 6.5v is unacceptable.
- Expensive Satco use ~0.60 amps at 12v. As you drop the voltage to 10.6v they will ramp up amps to 0.73 amp, after which they dim whilst holding current constant. They claim to be an 8w bulb, however they never exceed 7.7w and run at 7.2w normally.
- I didn't mention it above as I only have a couple of them so not worth the testing time: a 'Goodlite' 3500K 7w MR16 bulb uses 0.61 amps at 12v, which is 7.3w. These are different again, as you drop the voltage they keep ramping current upwards to compensate, with an apparent constant current cap at 1.15 amps, after which they dim.

So tl;dr; you need to budget one amp per bulb worst case if they're connected in parallel. So five bulbs could draw 5 amps of 12v.

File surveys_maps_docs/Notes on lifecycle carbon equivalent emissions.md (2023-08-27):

## Goal

- RIBA 2030 climate challenge of < 625 kg of embodied CO<sub>2e</sub> per m<sup>2</sup>
and < 35 kWh of operational energy per m<sup>2</sup> per year.
    - House has 312 m<sup>2</sup>, so this is 195 metric tonnes of embodied
    carbon and 10,920 kWh of operational energy per year.
    - RIBA uses a 60 year lifespan (the EU uses a 50 year lifespan).
- RIAI's target is < 450 kg of embodied CO<sub>2e</sub> per m<sup>2</sup>.
    - This is 140.4 metric tonnes for my house.

## Estimates for my house

Note https://epdireland.lca-data.com/processList.xhtml?stock=PUBLIC lists EPDs
publicly available for building components in Ireland. I note nothing there
on timber frames nor prefabricated floors.

https://www.igbc.ie/generic-data/ supplies estimates for some of the missing
common items.

- Timber seems to be -616 to -681 kg of embodied CO<sub>2e</sub>
per m<sup>3</sup>. God knows how many metres cubed of timber a timber framed
house might use, I assume it isn't a huge amount per m<sup>2</sup>. 
- CEM I (portland cement) is 763 kg of embodied CO<sub>2e</sub> per metric tonne.
- CEM III (used in readymix) is 371-512 kg of embodied CO<sub>2e</sub> per metric tonne.
- Solid concrete blocks appear to be 10.6 kg of embodied CO<sub>2e</sub>
per m<sup>2</sup>. A m<sup>2</sup> of concrete block weighs 142.5 kg, therefore
that is 74.4 kg of embodied CO<sub>2e</sub> per metric tonne.
- Steel girders is 1,490 kg of embodied CO<sub>2e</sub> per metric tonne.

You can get more detailed EPDs (yet to do):

- Sodra of Sweden supply the structural timber, mainly from Sweden and Finland.
- Roof trusses and/or rafters from Sodra or Balcas.
- Loose rafters from Glennon Bros mills.
- OSB by Coillte, Irish sourced timber.
- Plasterboard is from Gyproc, Irish manufacturer though surely the gypsum is
from abroad.

### Installation

- 114.2 metric tonnes for shell and foundations (366 kg CO<sub>2e</sub>
per m<sup>2</sup>, a non-PH NZEB house might be 267 kg CO<sub>2e</sub>
per m<sup>2</sup>, perhaps the +37% is a bit much, equally triple glazed
windows plus thicker insulation embodies lots more carbon).
- 2 metric tonnes for the lithium batteries.
- 2.5 metric tonnes for the hybrid inverter.
- 12.2 metric tonnes for the solar panels.
- ? for the steel girders pinning the insides together.
- ? for the thermal store.
- ? for heavy lorry transport of all the above.

Already above is 130.9 metric tonnes, this is close to the 140.4 limit.

Avoided:

- 1.5 metric tonnes by avoiding heat pump.

### During use

- 10 metric tonnes as lithium batteries would need replacing five times in sixty years.
- 5 metric tonnes as the hybrid inverter would need replacing two times in sixty years.
- 24.4 metric tonnes as the solar panels would need replacing twice in sixty years.
- ? metric tonnes as the windows would need replacing once in sixty years.

Avoided:

- Any refrigerant leakage from heat pumps or replacement thereof.

This definitely exceeds the RIAI challenge of < 450 kg of embodied
CO<sub>2e</sub> per m<sup>2</sup> as 170.3 metric tonnes is already
consumed (this is 545 kg of embodied CO<sub>2e</sub> per m<sup>2</sup>).

#### Operational carbon

- Annual operational energy use per year: 9360 kWh (30 kWh per m<sup>2</sup> per year)
    - Annual grid contribution: 2572 kWh
    - Annual grid demand: 2299 kWh

After offsetting winter by summer, mildly reduces overall CO<sub>2e</sub>
emitted by 106.2 kg per year. This is 6.4 metric tonnes over sixty years.

During winter, it is generally windier, plus we recharge the thermal
store and lithium batteries using cheap night rate electricity which
tends to mostly come from wind farms by definition, so we might in
practice do better than that amount of carbon saved.

## Assumptions

- Irish/UK housing (for a sample 200 m<sup>2</sup> house probably meeting
pre-2019 regs as house was in the UK) has a total lifecycle of:
    - A1-A3 Materials:
        - Masonry: 304 kg CO<sub>2e</sub> per m<sup>2</sup>.
        - Timber Frame: 179.9 kg CO<sub>2e</sub> per m<sup>2</sup>.
    - A4 Transportation:
        - Masonry: 4.3 kg CO<sub>2e</sub> per m<sup>2</sup>.
        - Timber Frame: 1.7 kg CO<sub>2e</sub> per m<sup>2</sup>.
    - A5 Construction:
        - Masonry: 39.2 kg CO<sub>2e</sub> per m<sup>2</sup>.
        - Timber Frame: 37.7 kg CO<sub>2e</sub> per m<sup>2</sup>.
    - B1-B5 Maintenance and Replacement:
        - Masonry: 18.4 kg CO<sub>2e</sub> per m<sup>2</sup>.
        - Timber Frame: 13.2 kg CO<sub>2e</sub> per m<sup>2</sup>.
    - B6 Energy:
        - Masonry: 376.5 kg CO<sub>2e</sub> per m<sup>2</sup>.
        - Timber Frame: 386.6 kg CO<sub>2e</sub> per m<sup>2</sup>.
    - B7 Water:
        - Masonry: 11.9 kg CO<sub>2e</sub> per m<sup>2</sup>.
        - Timber Frame: 11.1 kg CO<sub>2e</sub> per m<sup>2</sup>.
    - C1-C4 End of life:
        - Masonry: 26.9 kg CO<sub>2e</sub> per m<sup>2</sup>.
        - Timber Frame: 23.8 kg CO<sub>2e</sub> per m<sup>2</sup>.

- A certified passive house in Passive House Plus got 575 kg CO<sub>2e</sub> per
m<sup>2</sup> excluding PV modules, inverter etc.
    - Windows, doors and roof lights: 95 kg CO<sub>2e</sub> per
m<sup>2</sup>.
        - Windows and doors alone: 39 kg CO<sub>2e</sub> per
m<sup>2</sup> to install, 29 kg CO<sub>2e</sub> per
m<sup>2</sup> during use, 39 kg CO<sub>2e</sub> per
m<sup>2</sup> to dispose at end of life.
    - Substructure: 109 kg CO<sub>2e</sub> per m<sup>2</sup>.
    - Superstructure incl wood and insulation: 162 kg CO<sub>2e</sub> per m<sup>2</sup>.
    - MVHR + HP (three replacements): 119 kg CO<sub>2e</sub> per m<sup>2</sup>
    (24 to install, 94 during use, 1 to dispose at end of life).

- Lithium batteries a total lifecycle of 150-200 kg CO<sub>2e</sub> per kWh of capacity
 (source: https://www.energimyndigheten.se/globalassets/forskning--innovation/transporter/c243-the-life-cycle-energy-consumption-and-co2-emissions-from-lithium-ion-batteries-.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). This probably assumed a ten year lifespan.
    - Perhaps 73 kg CO<sub>2e</sub> per kWh of capacity to manufacture.
    - Note BYD Battery Box are cobalt free, and Lithium Ion Phosphate chemistry.
    - Ours is a 10.24 kWh system weighing 167 kg.
    - It has 96% efficiency.
    - BYD guarantee at least 60% of capacity will remain after ten years OR
    30.82 MWh of power has been supplied by a 10.24 kWh system (this is 3,010
    cycles).

- A Huawei 6kW hybrid inverter had a total lifecycle CO<sub>2e</sub> of 1504 kg,
 23% of which was production, 76% was use (through energy wasted by heat over its
 25 year assumed lifespan), and a fairly unbelievably low < 1% went on end of life
 (source: https://www.ske-solar.com/wp-content/uploads/2021/01/Zertifikat-Product-Carbon-Footprint-Report-f%C3%BCr-Huawei-SUN2000-6KTL-L1-Wechselrichter.pdf).
    - Our Sungrow unit is 10kW which would cost a bit more materials in production,
    but the batteries means only very rarely does its waste heat come from the grid.

- Solar panels have a total lifecycle CO<sub>2e</sub> of 615 kg per kW. Another
source says 242 kg CO<sub>2e</sub> per m<sup>2</sup>.

- A 6kW heat pump has a total lifecycle of 220-260 kg CO<sub>2e</sub> per kW of
capacity. A 40kW heat pump has a total lifecycle of around 130 kg CO<sub>2e</sub>
per kW of capacity. Lifespan was assumed to be fifteen years. Source: https://www.cibsejournal.com/technical/embodied-energy-the-whole-picture/

- In 2022 the Irish electrical grid emitted 0.389 kg of CO<sub>2e</sub> per kWh
generated. This is not delivered however, apparently the Irish electrical grid
had transmission losses of 8% in 2022. This gives 0.42 kg of CO<sub>2e</sub> per
kWh delivered.

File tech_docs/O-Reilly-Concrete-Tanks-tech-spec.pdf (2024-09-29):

# Precast Concrete Tanks

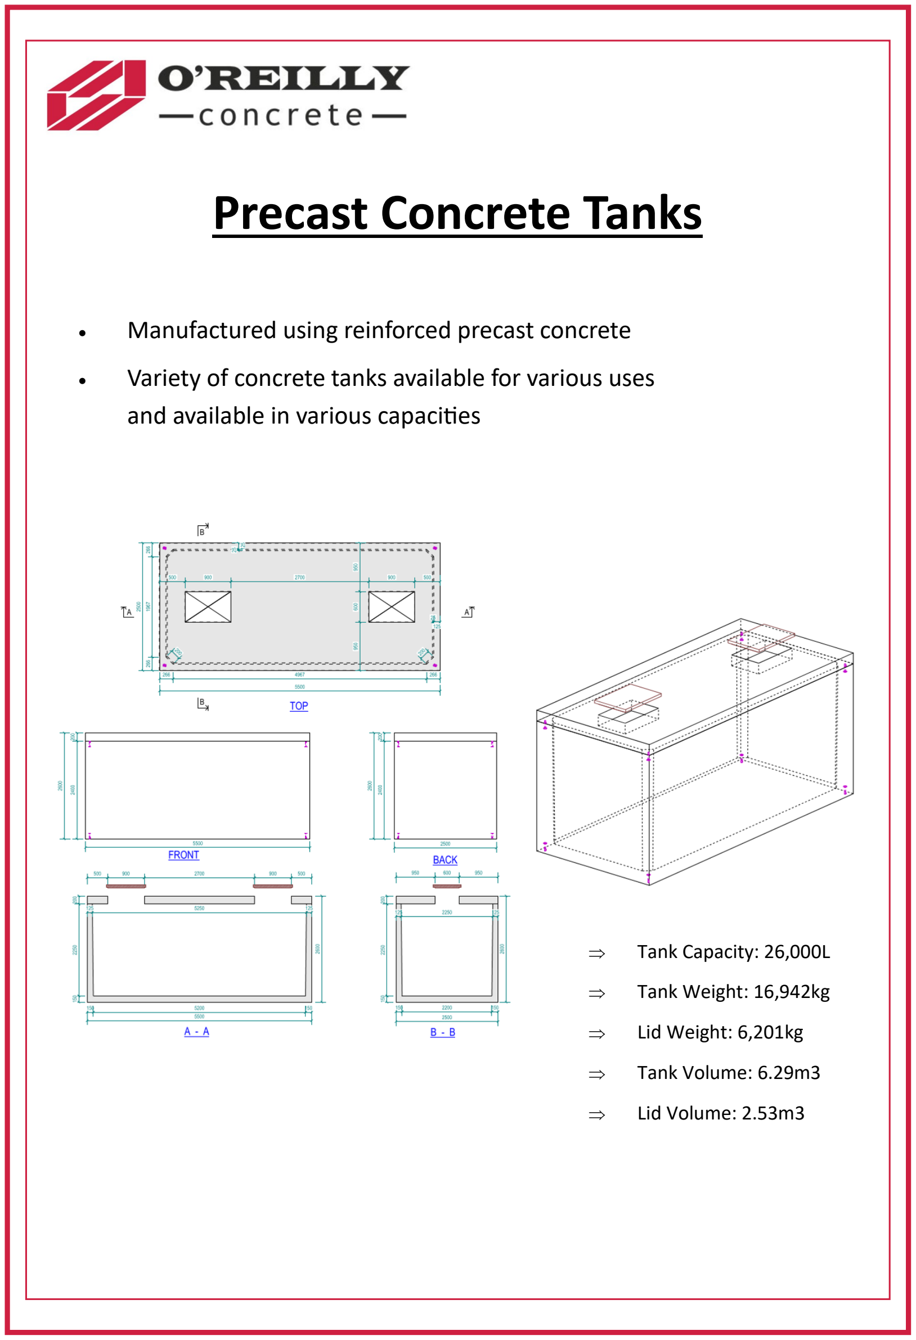
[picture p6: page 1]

- Manufactured using reinforced precast concrete
- Variety of concrete tanks available for various uses and available in various capacities
Þ | Tank Capacity: 26,000L
Þ | Tank Weight: 16,942kg
Þ | Lid Weight: 6,201kg
Þ | Tank Volume: 6.29m3
Þ | Lid Volume: 2.53m3

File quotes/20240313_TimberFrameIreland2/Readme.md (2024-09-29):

# Quote

Main house: €228,214 inc VAT to pre-first fix (€96,370 + €43,720 + €2,690 + €6,740 + €860 superstructure; €50,690 substructure). This is €622 inc VAT per sqm.

Outhouse: not quoted

Obviously compared to the LL Structures quote this is much, much cheaper, but see its quote summary for more about that.

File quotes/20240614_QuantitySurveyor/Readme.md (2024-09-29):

# Quantity Surveyor Estimate to Completed

Main house: €966,992 inc VAT to completed. This is €3,245 inc VAT per sqm.

- Substructure: €94,924 inc VAT.
- Superstructure: €318,466 inc VAT.
- External walls excl finish: €24,808 inc VAT.
- Stairs: €17,025 inc VAT.
- Internal joinery excl finish: €31,245 inc VAT.
- Glazing non-roof: €56,482 inc VAT.
- Glazing roof: €36,318 inc VAT.
- External wall render + charred larch + fascia & soffit: €58,202 inc VAT.
- External roof finishes excl drainage: €36,936 inc VAT.
- Roof drainage: €8,798 inc VAT.
- Internal finishes:
    - Walls incl plasterboard, tanking and tiling excl insulation: €60,879 inc VAT.
    - Floors: €30,219 inc VAT.
    - Ceilings incl plasterboard and insulation: €35,963 inc VAT.
    - Painting: €15,962 inc VAT.
    - Kitchen, wardrobes, cloaks: €11,917 inc VAT.
    - Heating & plumbing & ventilation: €43,124 inc VAT.
    - Electrical: €44,650 inc VAT.
- Necessary foulwater drainage: €16,104 inc VAT.
- Waste disposal: €10,215 inc VAT.
- Scaffolding: €14,755 inc VAT.

- Greenhouse: €70,056 inc VAT.
- Outhouse: €79,450 inc VAT.
- Entrance wall, fencing, walled garden: €42,634 inc VAT.
- Driveway and footpaths: €31,708 inc VAT.
- Rainwater harvesting & reed bed: €7,945 inc VAT.

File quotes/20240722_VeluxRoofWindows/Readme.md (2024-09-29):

NOTE that this quote is for the 006730, NOT the 008230. These have a u-value of 0.83 W/m2K. An additional double glazed panel would need to be fitted to each to turn them into the 008230.

This quote: €21,613 inc VAT.

The Fakro quote: €21,532 inc VAT.

So even at triple not quintuple glazed, the Fakros are cheaper.

The Fakros can't self open, they are only manual, so it isn't a like for like comparison.

Also the Fakros don't have as good u-values, 0.70 W/m2K vs 0.57 W/m2K.

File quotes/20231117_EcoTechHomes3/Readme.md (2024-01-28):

# Quote

Main house: €361,297 inc VAT to first fix. This is €1,212 inc VAT per sqm.

Outhouse: not quoted

# Includes:

- Main house to first fix.
- Insulated floor for greenhouse
- Roof slates
- Flat roof (EPDM)
- Plasterboard, **but not fitted**
- Floors: 0.10; Walls: 0.16; Roof (sloped): 0.16; Roof (flat): 0.11. Floor is typical KORE insulated slab.
- **Guaranteed air tightness < 0.6 ACH to meet passive spec**

# Excludes:

- Structural Engineering (+10k cost)
- Groundworks (+20k cost)
- External windows and doors (+50k cost)
- Wiring (+10k cost)
- Plumbing (+4k cost)
- External block leaf (plastered) (+53k cost assuming 333 m2 of exterior wall at €160 per sqm plastered)
- External footpaths (+26k cost)
- Glass Ballustarding (+16k cost)
- Stairs (+5k cost)
- Internal doors (+12k cost including skirting and window sills)
- Rubbish removal
- Site costs such as scaffolding, welfare cabin for workers, waste disposal etc.

# Payment terms:

-  6.5%: Initial deposit
- 18.0%: Prepayment of foundations
- 16.5%: Prepayment of offsite manufacture
- 42.0%: Prepayment of install
- 14.0%: Prepayment of roof slates
-  3.0%: After completion

# Other notes:
- Closest competing quote is TimberFrameIreland.

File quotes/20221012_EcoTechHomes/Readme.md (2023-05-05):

# Quote

Main house: €605,961 inc VAT to builder's finish. This is €1,961 inc VAT per sqm. You should assume +5% price inflation since the quote i.e. €636,259 inc VAT (€2,059 inc VAT per sqm).

Outhouse: not quoted

# Includes:

- Main house and immediate exterior (e.g. footpaths) to builder's finish.
- Insulated floor for greenhouse
- External block leaf (plastered)
- Roof slates
- Internal plasterboarding (though unpainted)
- Internal doors (note they look cheap MDF units)
- Internal stairs (solid wood, probably don't want that)
- Gutters and downpipes
- Excavation
- Scaffolding
- Waste removal
- Floors: 0.11; Walls: 0.15; Roof (sloping): 0.14; Roof (flat): 0.11.
- Internal walls: 100mm quilt wool insulation.
- **Guaranteed air tightness < 0.6 ACH to meet passive spec**

# Excludes:

- Structural Engineering (+10k cost)
- M&E engineering (+10k cost)
- Soil removal
- Sanitary ware for bathrooms (though pipe fittings are included)
- Greenhouse

# Payment terms:

- 10%: Deposit
- 23%: Completion of foundation
- 23%: Completion of roof
- 18%: Completion of external surfaces
- 18%: Completion of internal surfaces
- 8%: Final payment

# Other notes:

- Nicely compatible with the stage drawdown payments Irish banks use.
- Cheaper than the QS builder's finish estimate (€633k), but does less stuff -- I reckon €20k of stuff from the QS estimate is obviously removed. I would wonder if the quote might rise slightly when he sees construction detail, as the quote did not seem overly detail focused.
- Looks weirdly similar in technology and spec to the Eco 220 system from https://www.llstructures.ie/wall-systems/
who are a Galway based timber frame builder also using cellulose insulation.
So much so in fact so I've downloaded the ACDs from there into here, as
I reckon them almost identical.
- The only other 220 mm thick cellulose filled panel I can find in Ireland
is Carrigaline's Eco Timber Systems https://ecotimbersystems.ie/timber-systems/wall-systems/220-passive/.
Note that it is within PHPP, which will save time.

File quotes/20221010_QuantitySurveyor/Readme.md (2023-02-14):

# Quote (actually for Cygnum Reflect 200 system with 300 mm thick roof panels)

Main house: €144,145 inc VAT for superstructure only. This is €466 inc VAT per sqm.

Outhouse: not quoted

Cygnum systems brochure: https://cygnum.ie/wp-content/uploads/2016/09/Cygnum-brochure-8pgA4-2014-version-proof5.pdf

# Includes:

- Walls: 0.15 (with external block leaf); Roof: 0.14.
- Structural Engineering and system design work
- Air tightness test. I don't know how this works when they don't fit the windows and doors. It will meet NZEB, unsure if it would meet PH spec (I would assume it will).

# Excludes:

- Groundworks
- Foundations (+47k cost)
- External windows and doors (+69k cost)
- Wiring (+10k cost)
- Plumbing (+4k cost)
- External block leaf (plastered) (+53k cost assuming 333 m2 of exterior wall at €160 per sqm plastered)
- External footpaths (+26k cost)
- Roof slates (+25k cost)
- Glass Ballustarding (+16k cost)
- Stairs (+5k cost)
- Internal doors (+12k cost including skirting and window sills)
- Rubbish removal
- Site costs such as scaffolding, welfare cabin for workers, waste disposal etc.

# Payment terms:

Unsure

# Other notes:

- Very similarly priced to the FutureTek quote. As in, within a few grand.
- Comes to €447k inc VAT to Builder's Finish, which looks cheap compared to the EcoTech quote of €636k. However this would be all direct labour, with all the attendent risk and hassle and time delays and stress on me.

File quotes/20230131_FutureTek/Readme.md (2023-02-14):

# Quote

Main house: €147,833 inc VAT for superstructure only. This is €478 inc VAT per sqm.

Outhouse: not quoted

Kingspan systems brochure: https://www.futuretek.ie/wp-content/uploads/TEK-172-mm-Standard-Details-Feb-16.pdf

# Includes:

- Walls: 0.15 (with external block leaf); Roof: 0.15.
- Structural Engineering and system design work
- Air tightness test < 0.6 ACH guaranteed. Not sure how this works when they don't fit the windows and doors?

# Excludes:

- Groundworks
- Foundations (+47k cost)
- External windows and doors (+69k cost)
- Wiring (+10k cost)
- Plumbing (+4k cost)
- External block leaf (plastered) (+53k cost assuming 333 m2 of exterior wall at €160 per sqm plastered)
- External footpaths (+26k cost)
- Roof slates (+25k cost)
- Glass Ballustarding (+16k cost)
- Stairs (+5k cost)
- Internal doors (+12k cost including skirting and window sills)
- Rubbish removal
- Site costs such as scaffolding, welfare cabin for workers, waste disposal etc.

# Payment terms:

Unsure

# Other notes:

- Very similarly priced to the Cygnum quote. As in, within a few grand.
- Comes to €451k inc VAT to Builder's Finish, which looks cheap compared to the EcoTech quote of €636k. However this would be all direct labour, with all the attendent risk and hassle and time delays and stress on me.

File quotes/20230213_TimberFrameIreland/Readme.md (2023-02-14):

# Quote

Main house: €192,462 inc VAT to first fix (€92,620 + €15,240 + €2,690 + €6,740 + €860 superstructure; €51,420 substructure). This is €622 inc VAT per sqm.

Outhouse: not quoted

# Includes:

- Main house to first fix.
- Insulated floor for greenhouse
- **Structural Engineering**
- Floors: 0.10; Walls: 0.15; Roof: 0.11. Floor is typical KORE insulated slab.
- Air tightness test?

# Excludes:

- Groundworks
- External windows and doors (+69k cost)
- Wiring (+10k cost)
- Plumbing (+4k cost)
- External block leaf (plastered) (+53k cost assuming 333 m2 of exterior wall at €160 per sqm plastered)
- External footpaths (+26k cost)
- Roof slates (+25k cost)
- Glass Ballustarding (+16k cost)
- Stairs (+5k cost)
- Internal doors (+12k cost including skirting and window sills)
- Rubbish removal
- Site costs such as scaffolding, welfare cabin for workers, waste disposal etc.

# Payment terms:

- 10%: Initial deposit
- 40%: Prepayment of offsite manufacture
- 40%: Prepayment of delivery
- 10%: After completion

# Other notes:
- First floor is posi joists, with all the benefits and annoyances that brings.
- Comes to €442k inc VAT to Builder's Finish, which is a touch cheaper than FutureTek (€451k) or Cygnum (€447k).
    - However, they *guarantee* the substructure will match the superstructure which the other two do not, which is a BIG difference.

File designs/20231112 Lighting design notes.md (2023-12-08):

Main living space is approx 60 m2 (12m x 5m)

Lighting in living space when on full is approx 11k (flood) + 22k (flood) + 11k (downlights) + 4k (LED strip) = 48k lumen.

This results in a maximum lux of around 800, which is quite high :)

However because we are also lighting the walls and ceilings one might in fact only get around 400 lux.

Task intensive (e.g. food prep, work office) should be around 500 lux.

Libraries should be 400 lux.

Gyms and bedrooms are typically 250 lux.

Corridors are 75 lux.

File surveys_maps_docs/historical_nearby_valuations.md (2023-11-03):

All data is from https://www.propertypriceregister.ie/

2023-02-14: 24 Ard Na Si, €390k.

- Four bedrooms, four bathrooms, BER B2, 316 m<sup>2</sup>. €1,234 per sqm.

2022-05-08: 36 Ard Na Si, €265k.

- Three bedrooms, BER C2, 151 m<sup>2</sup>, built 2009. €1,755 per sqm.

2021-12-06: 32 Ard Na Si, €300k.

- Five bedrooms.

2020-10-30: 2 Ard Na Si, €218k.

- Four bedrooms.

2019-12-20: 2 Ard Na Si, €176k.

2019-12-18: 37 Ard Na Si, €230k.

2019-10-02: 27 Ard Na Si, €260k.

2019-08-08: 15 Ard Na Si, €238k.

2019-05-08: 32 Ard Na Si, €200k.

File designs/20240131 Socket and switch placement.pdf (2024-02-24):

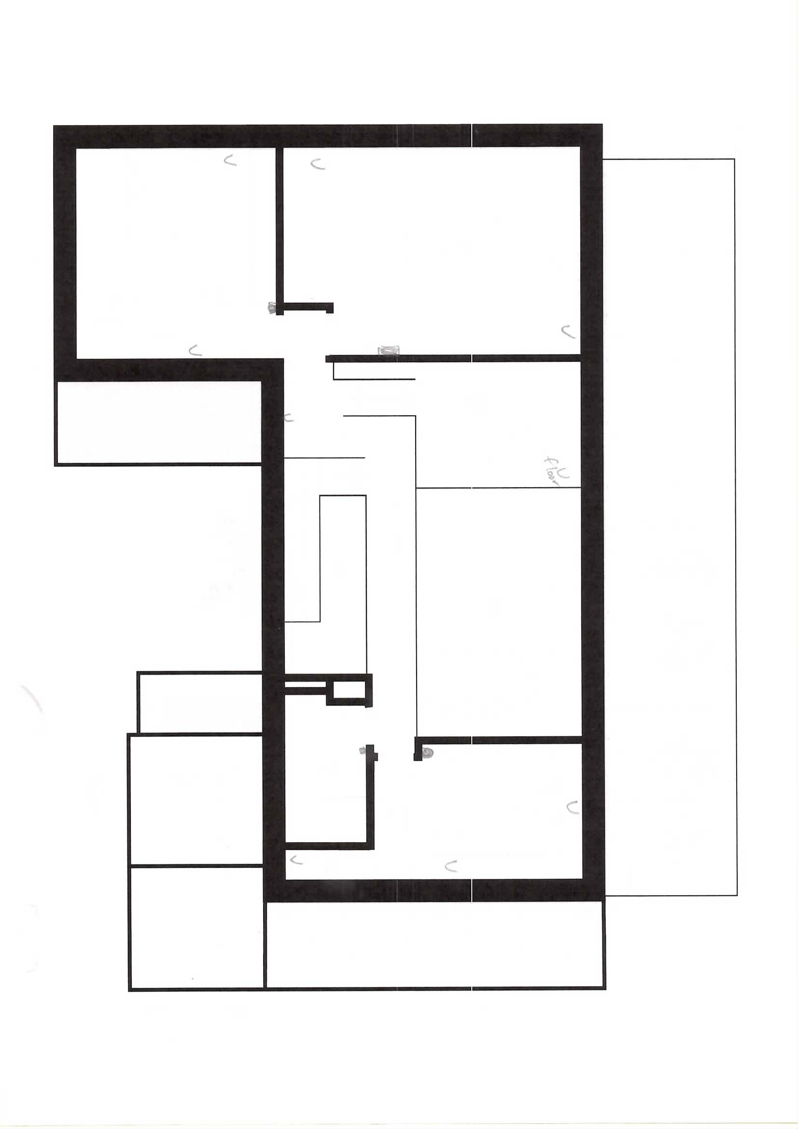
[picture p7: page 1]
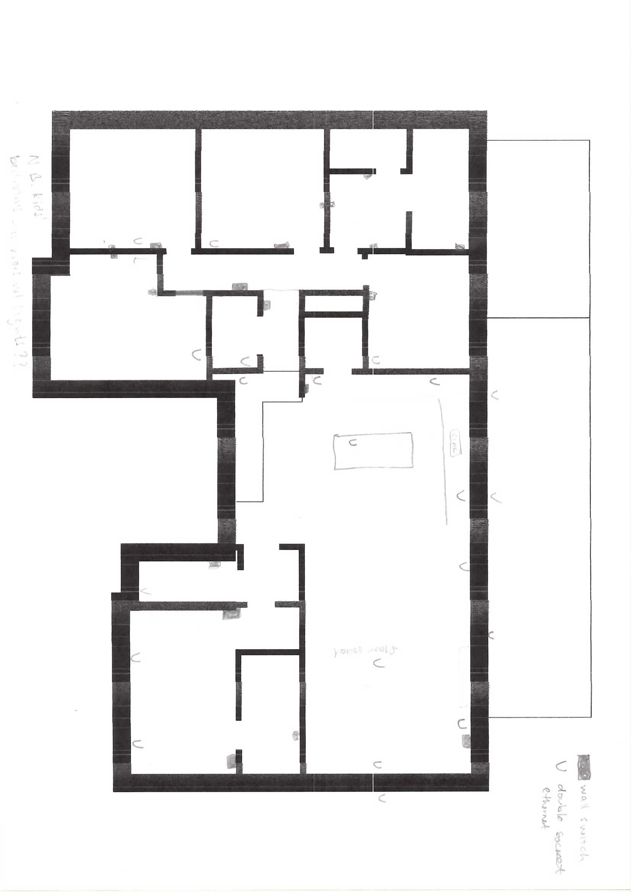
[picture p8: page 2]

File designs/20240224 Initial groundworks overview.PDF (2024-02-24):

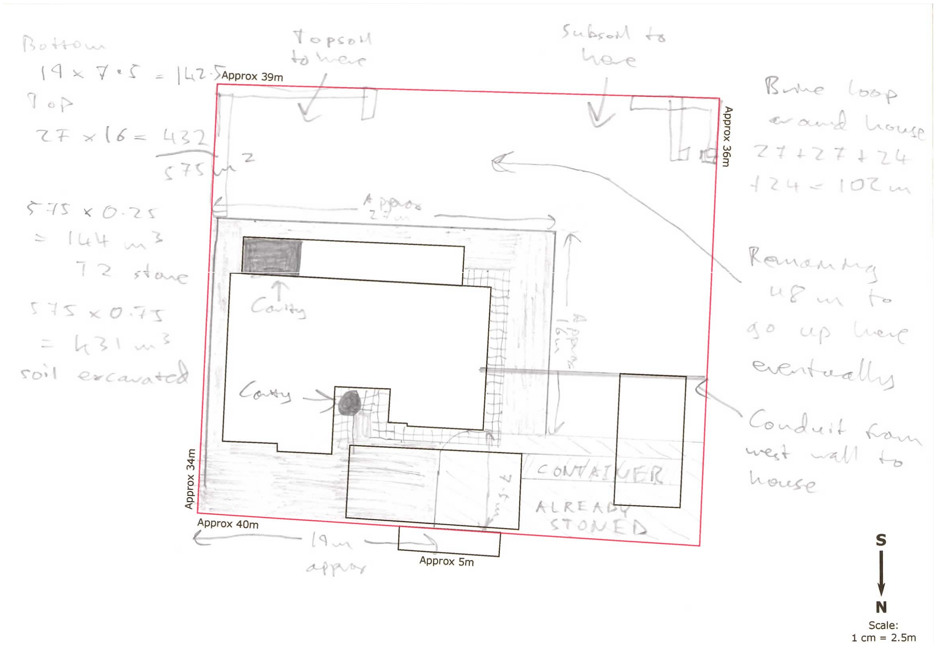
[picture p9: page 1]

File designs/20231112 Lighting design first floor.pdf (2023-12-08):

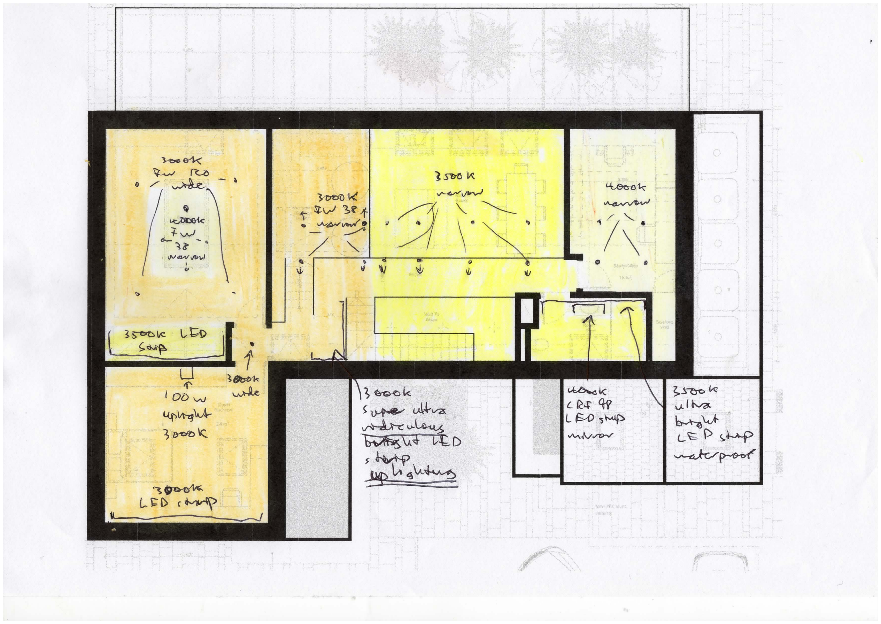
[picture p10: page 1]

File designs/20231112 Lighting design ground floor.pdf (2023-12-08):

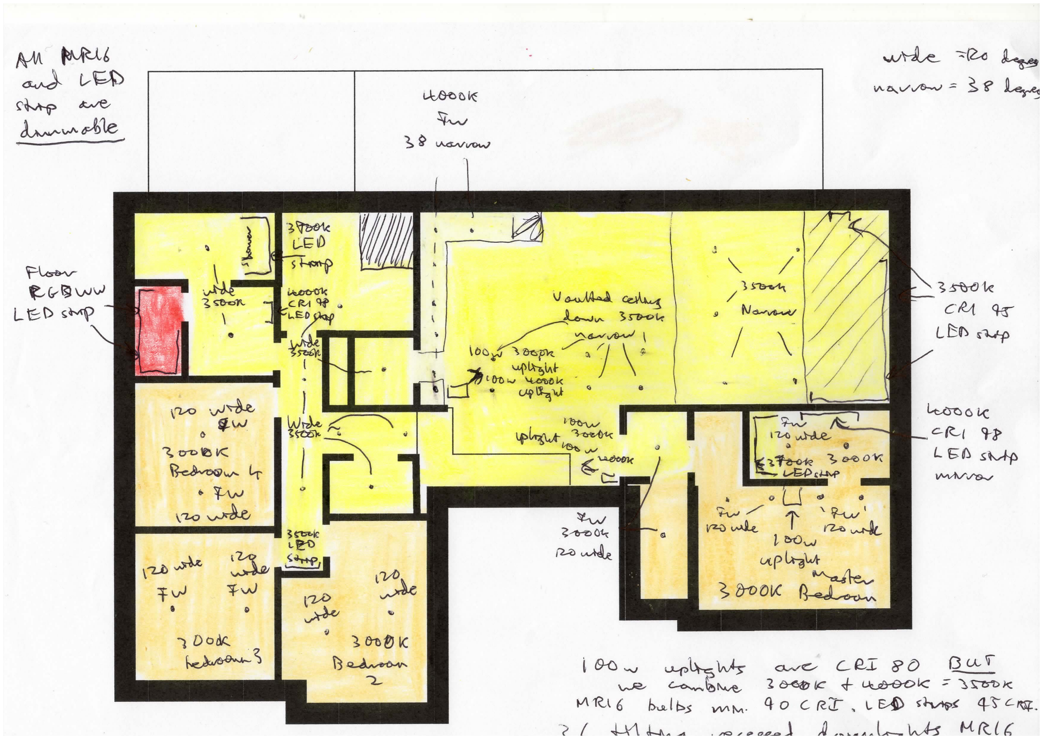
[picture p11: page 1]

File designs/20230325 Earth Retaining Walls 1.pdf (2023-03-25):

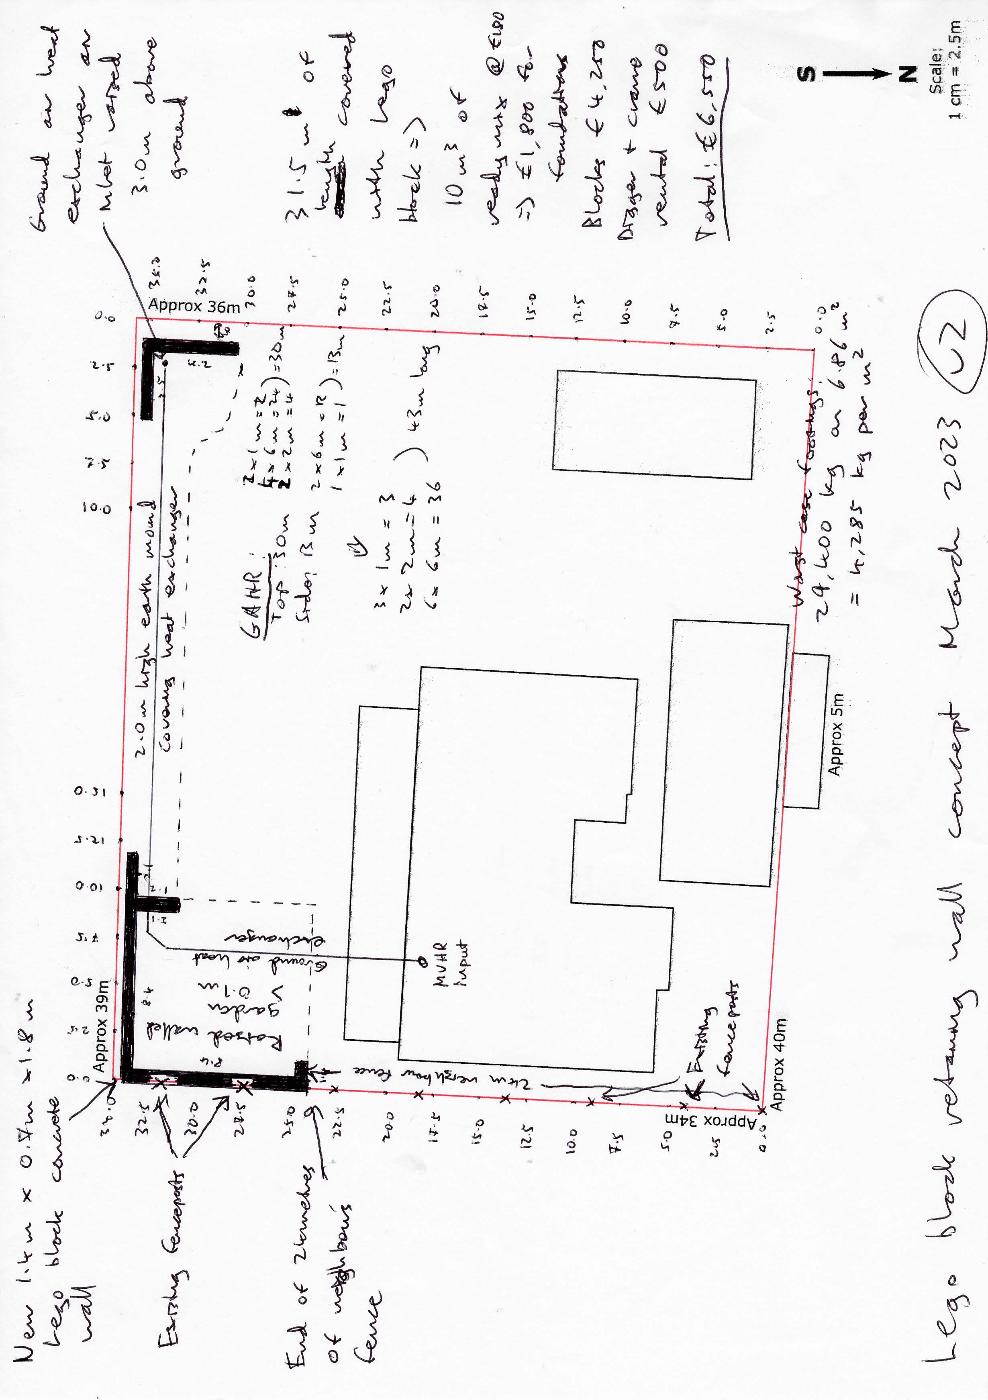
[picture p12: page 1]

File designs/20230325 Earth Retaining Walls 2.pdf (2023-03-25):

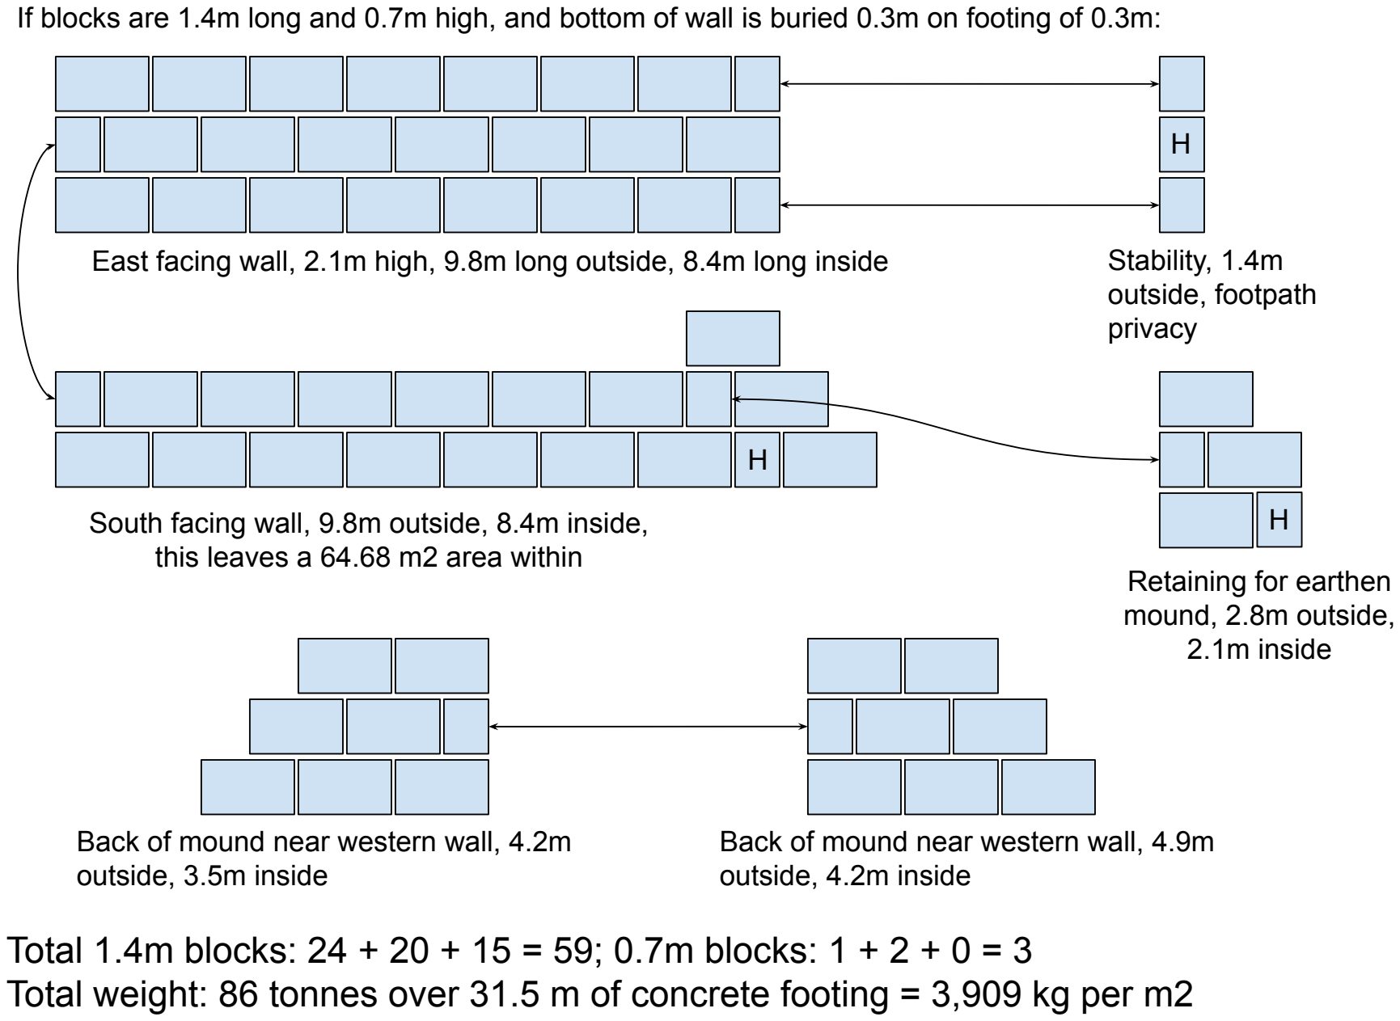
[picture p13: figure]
this leaves a 64.68 m2 area within; Retaining for earthen mound, 2.8m outside, 2.1m inside; Stability, 1.4m outside, footpath privacy; Back of mound near western wall, 4.2m outside, 3.5m inside; Back of mound near western wall, 4.9m outside, 4.2m inside

If blocks are 1.4m long and 0.7m high, and bottom of wall is buried 0.3m on footing of 0.3m:

East facing wall, 2.1m high, 9.8m long outside, 8.4m long inside

South facing wall, 9.8m outside, 8.4m inside,

## Total 1.4m blocks: 24 + 20 + 15 = 59; 0.7m blocks: 1 + 2 + 0 = 3 Total weight: 86 tonnes over 31.5 m of concrete footing = 3,909 kg per m2

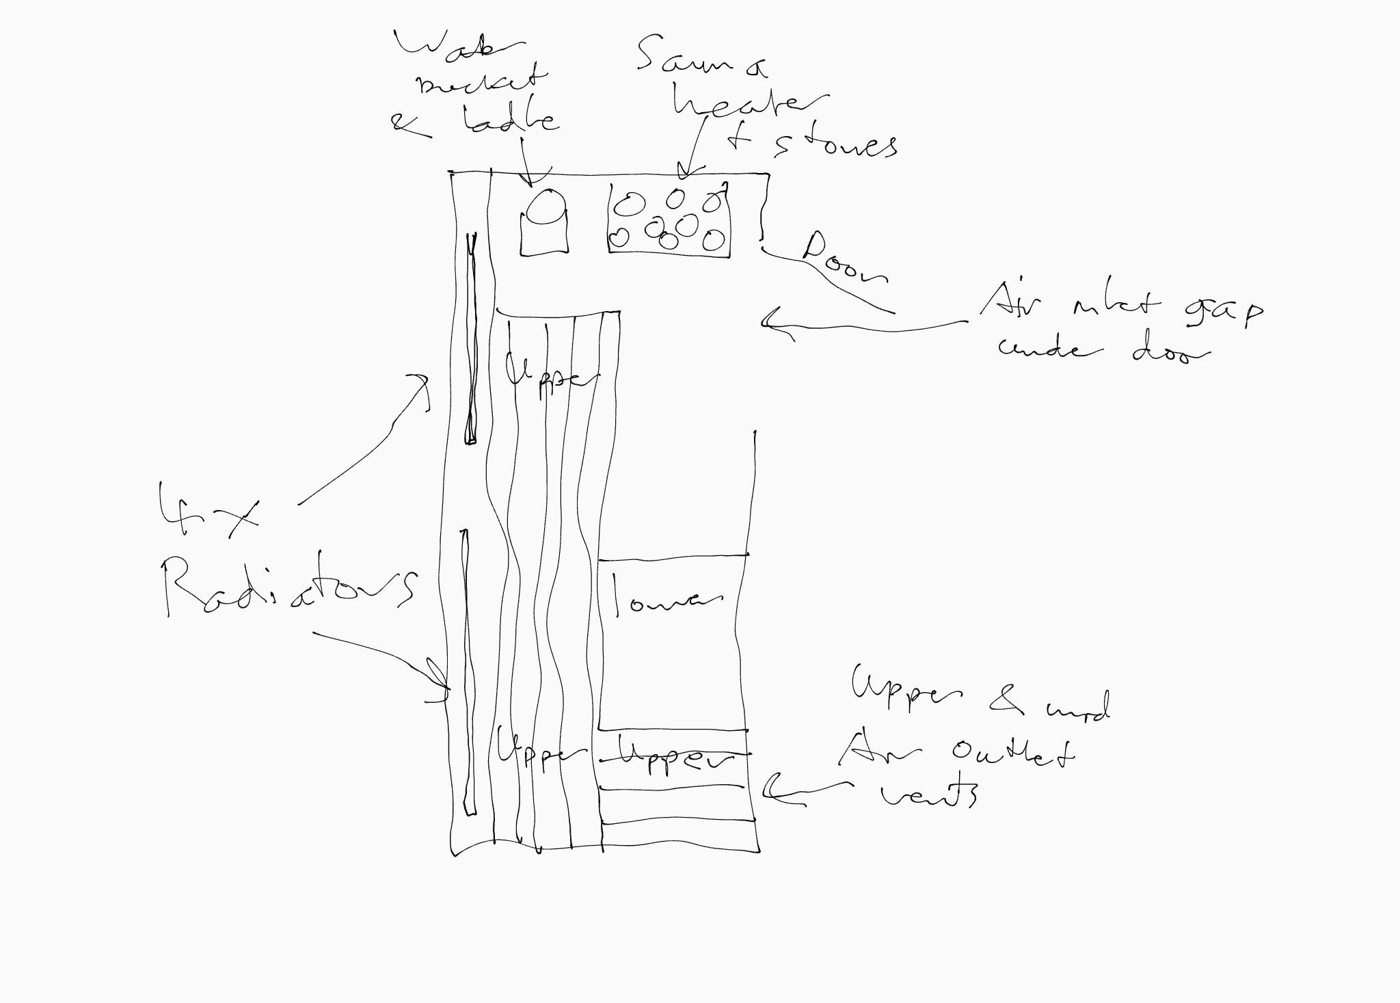
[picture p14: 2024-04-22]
designs/20240301_sauna_radiators1.png

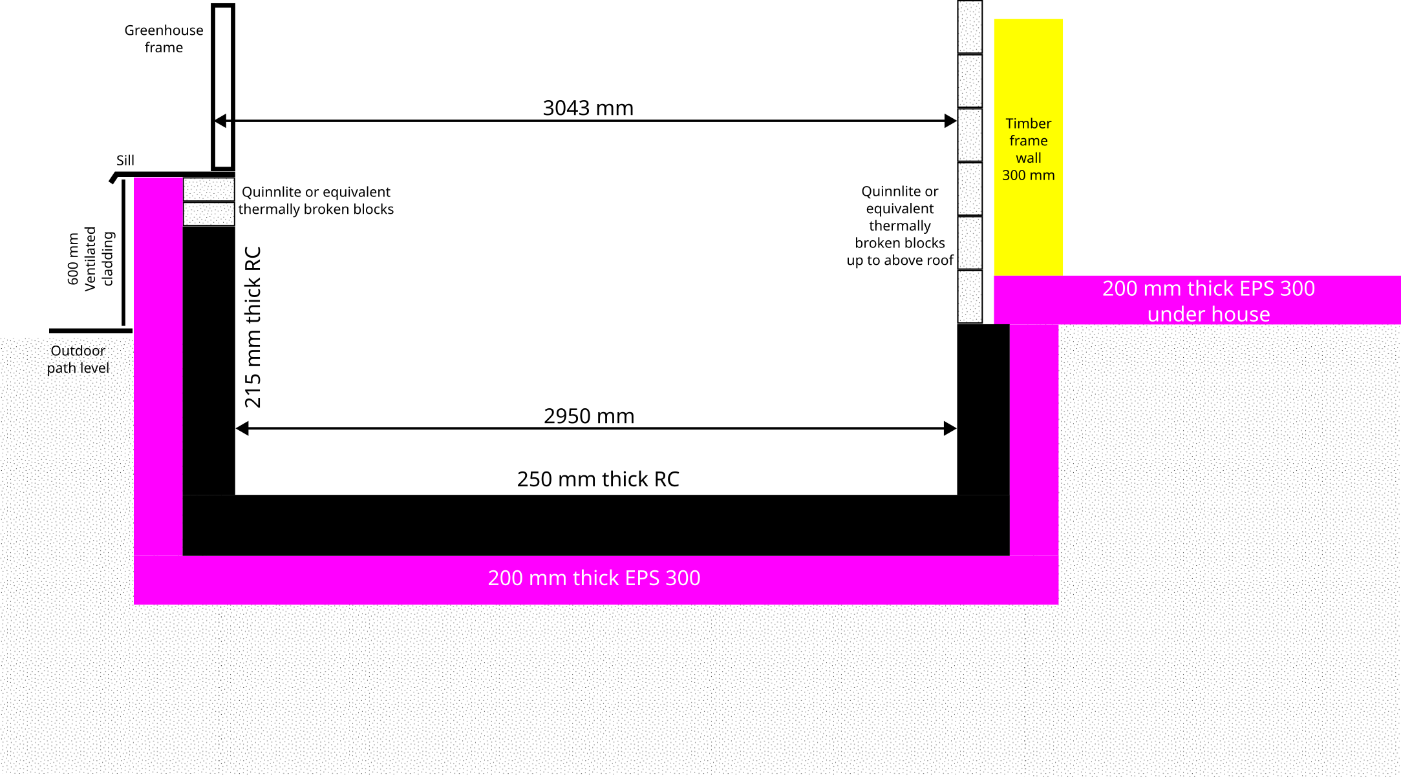
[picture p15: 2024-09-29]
designs/20240907_custom_underground_tank1a.png

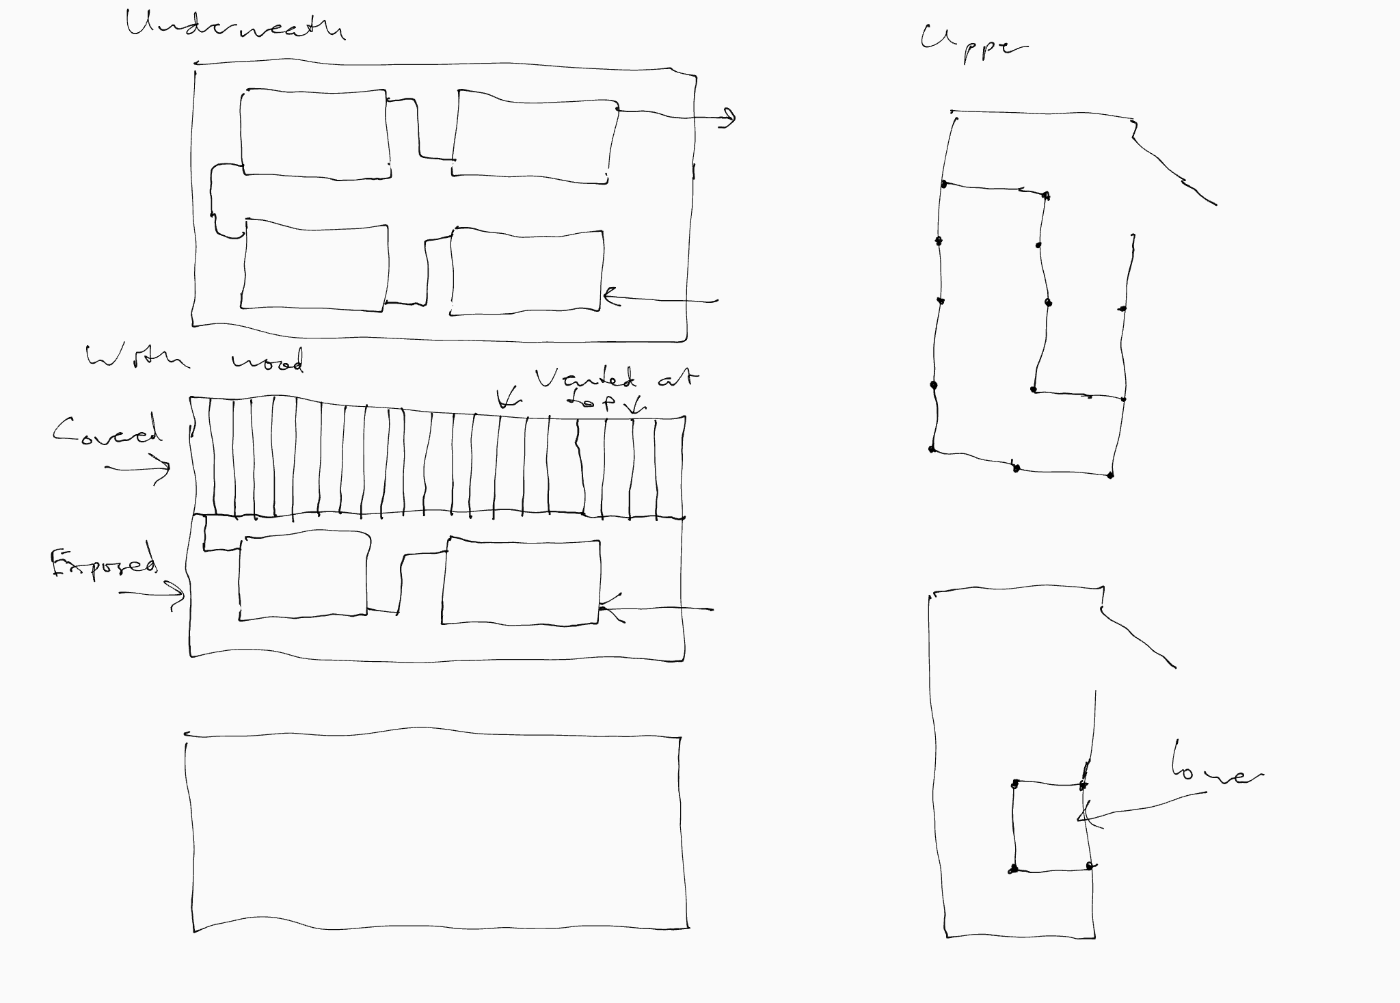
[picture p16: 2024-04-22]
designs/20240301_sauna_radiators2.png

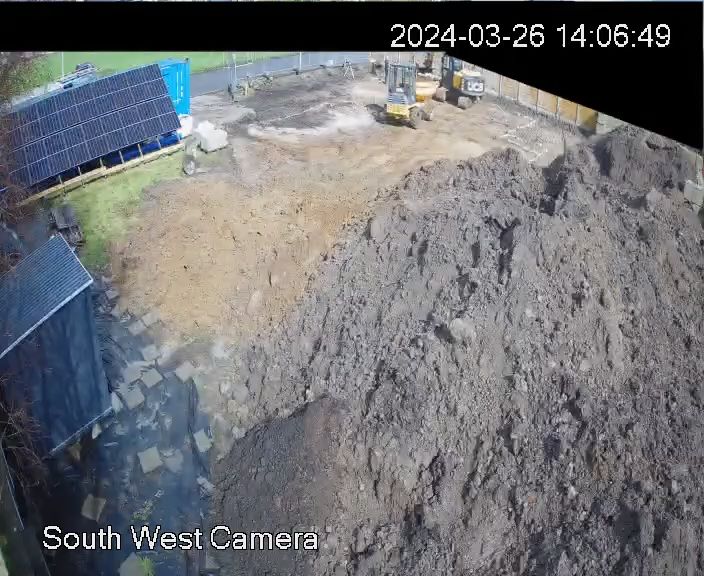
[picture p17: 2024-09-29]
images/202403/South West - 2024-03-26 14.06.51.jpg

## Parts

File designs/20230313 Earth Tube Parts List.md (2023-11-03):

30 metres next to ditch. Rises 1.2m from 4% slope. That's five six metre pipes.
1 metre at 45 degree angle.
13.75 metres from ditch to house. Rises 0.4m from 3% slope. That's two six metre pipes plus two one metre pipes OR three six metre pipes with four metres spare OR two six metre pipes plus one three metre pipe with one metre spare.
At air inlet, top of pipe would be 0.2m from surface.
Needs to rise by 2.2m to reach inlet. This will take more than two 1m lengths,
as 1m is vertical, 1m is at 45 degrees = 0.707m, leaving 0.5m.
BUT will chop a 0.4m section off the 30 metre length (7m + 0.7m + 30m + 0.7m = 38.4m,
so we are 0.4m too long). So, 0.7m rise from ground, then one
metre pipe = 1.7m, then plus 0.4m = 2.1m.

Part numbers are from https://github.com/ned14/HouseBuild/blob/main/tech_docs/Awadukt%20Thermo%20Parts%20List.pdf

Stephen's plan (40 metres of pipe):

(This list does not account for spares, which it probably ought to)

1. 6x 170961-002 Pipe DN 200 6m, each comes with a single fit sleeve
2. 4x 170641-002 Pipe DN 200 1m, each comes with a single fit sleeve. Three are for the turns, one is for extra to the condensor.
3. 4x 417021-001 Bend DN 200 45 degree, each comes with a single fit sleeve
4. 1x 417051-001 Double fit sleeve DN 200 to connect unsleeved pipe end to air inlet
5. 1x 170188-003 Air Inlet DN 200 for above ground external air entry
6. 2x 170198-001 Air inlet filter DN 200
7. 1x 227785-003 Condensation collection shaft DN 315/200 for underneath the house
8. 1x 175584-001 Condensation collection shaft cast iron cover for floor of utility room over the shaft
9. 1x 353254-001 GAHE sealing collar DN 315 (up to 4 bar ground water pressure) for where condensation chamber top enters building under floor of utility room
10. 2x 176520-003 Lubricant 250 g

Niall's plan (48 metres of pipe):

1. 7x 170961-002 Pipe DN 200 6m, each comes with a single fit sleeve. Five up top, two on side.
2. 1x 170651-002 Pipe DN 200 3m, each comes with a single fit sleeve. For pipe reaching condensor. Expecting to cut off 1 metre, which would be spare.
3. 3x 170641-002 Pipe DN 200 1m, each comes with a single fit sleeve. Each is for a turn.
4. 4x 417021-001 Bend DN 200 45 degree, each comes with a single fit sleeve
5. 3x 417051-001 Double fit sleeve DN 200, one to connect unsleeved pipe end to air inlet; one to extend air inlet pipe with 0.4 metre length spare; one for use with 1.0 metre spare.
6. 1x 170188-003 Air Inlet DN 200 for above ground external air entry
7. 2x 170198-001 Air inlet filter DN 200
8. 1x 227785-003 Condensation collection shaft DN 315/200 for underneath the house
9. 1x 175584-001 Condensation collection shaft cast iron cover for floor of utility room over the shaft
10. 1x 353254-001 GAHE sealing collar DN 315 (up to 4 bar ground water pressure) for where condensation chamber top enters building under floor of utility room
11. 2x 176520-003 Lubricant 250 g

https://shop.inovatech.de/ quote €4,668 inc VAT for most of the above. Not including delivery.
    - 6m pipes cost €334.24 each (€55.71 per metre). 26.75 kg each.
    - 3m pipes cost €195.96 each (€65.32 per metre, €63.33 in bulk). 13.98 kg each.
    - 1m pipes cost €84.22 each. 6 kg each.
    - 45 degree couplers €67.73 each. 1.31 kg each.
    - Double socket sleeve €59.93 each. 1 kg.
    - Air inlet €675.89 each. 9.6 kg.
    - Condensation collection shaft €743.05 each. 34.5 kg.
    - Condensation iron cover €571.28 each. 35 kg.
    - Lubricant €4.64 each
    - MISSING sealing collar (RRP €180.70)
    - MISSING air inlet filter (RRP €33 for coarse, €153 for fine)
    
Generally seems to be a 10-15% discount over RRP.

Shipping weight: 187 + 14 + 5 + 1 + 10 + 35 + 35 = 287 kg

Biggest Hertz van rental: 3.7m long, 1.75m wide, 1.8m high. This would fit eight pipes across, nine pipes high, which is 72 three metre length pipes.
    - €215 to rent for five days. First 1,590 km is free, after 19c/km ex VAT. It is 2,900 km round trip. So cost is €521.
    - €500 for ferry with van Rosslare to Cherbourg.
    - At 10 litres/100km, would use 290 litres diesel. At €1.70 per litre, €500.
    - Hotels and food still needed.

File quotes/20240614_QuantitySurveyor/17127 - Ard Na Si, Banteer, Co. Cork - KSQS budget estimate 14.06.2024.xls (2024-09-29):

 | Description |  | Quantity | Unit | Rate | Total
Trade : | 1 | SUBSTRUCTURE
 | SUBSTRUCTURE
 | Works to substructure - based on invoice client recieved
1 | ^^^380 tonnes of stone, supply and installation of 150m of brine loop to 1.5m depth, removal of 370 tonnes of soil, rental of 13 tonne digger for a week, and all associated labours and costs. |  | 1.00 | Item | €22652.86 | €22652.86
 | Insulated Foundation Structure
2 | ^^^Allow for supply and installation of substructure element from Longlife Structures - Based on quote from the 12.02.2024 |  | 1.00 | Item | €56672.53 | €56672.53
3 | ^^^Allow for attendances on the subcontractor (loadall, supervision, use of small plant, skips, etc.) |  | 1.00 | Item | €2833.63 | €2833.63
 | Sundries
4 | ^^^Allow an item for underfloor drainage pipes complete |  | 1.00 | Item | €300.00 | €300.00
5 | ^^^Allow for weep holes to the perimeter - assume every 5 m |  | 1.00 | Item | €525.00 | €525.00
6 | ^^^EPDM to door threshold |  | 1.00 | Item | €650.00 | €650.00
SUBSTRUCTURE |  | Total : | €83634.02
Trade : | 2 | TIMBERFRAME
 | TIMBERFRAME
1 | ^^^PC Sum of Ç257,391.82 for supply and installation of timberframe systems - Based on Long Life Structure 220 Eco Gutex system |  | 1.00 | Item | €257391.82 | €257391.82
2 | ^^^Allow for attendances on the subcontractor (loadall, supervision, use of small plant, skips, etc.) |  | 1.00 | Item | €12869.59 | €12869.59
3 | ^^^Allow for supply of 70mm rockwool sound insulation for between internal stud walls - Client to fit (roughly 263m2) |  | 1.00 | Item | €2919.48 | €2919.48
4 | ^^^Allow for supply of 100mm rockwool sound insulation for between floor joists - Client to fit (roughly 140m2) |  | 1.00 | Item | €1914.79 | €1914.79
5 | ^^^Allow for Second airtightness test |  | 1.00 | Item | €450.00 | €450.00
6 |  |  |  | noid
 | Stud Partitions - To Conceal Services (PROVISIONAL)
 | Timberwork; Structural and First Fixings
7 | ^^^Timber stud partition comprising of 100 x 50mm Vertical studs, head and sole plates and noggins. - Plasterboard included elsewhere |  | 53.00 | m2 | €28.00 | €1484.00
8 | ^^^Allow for insulating between the studs with 100mm roll |  | 53.00 | m2 | €18.00 | €954.00
9 |  |  |  | noid
 | Stud Partitions - Staggered Studs
 | Timberwork; Structural and First Fixings
10 | ^^^Timber stud partition comprising of 100 x 50mm Vertical studs, head and sole plates and noggins. - Plasterboard included elsewhere |  | 93.00 | m2 | €28.00 | €2604.00
TIMBERFRAME |  | Total : | €280587.68
Trade : | 3 | EXTERNAL WALLS
 | EXTERNAL WALLS
 | Lintels
 | "Spanlite" or equivalent precast concrete lintol reinforced with and including 2 No. 12 mm diameter high yield bars hoisted and bedded in cement mortar to I.S. 325 (iii) in concrete block walls and propped as required
1 | ^^^100 x 65 mm lintels |  | 59.00 | m | €14.00 | €826.00
 | Blockwork
 | Solid concrete blockwork to I.S.20 type A having a compressive strength of 7.5N/mm2; nominal size 440 x 215 x 102.5 mm bedded and jointed in cement mortar to designation I.S.325 (iii) in
 | Cavity Walls
2 | ^^^100 mm thick. |  | 348.00 | m2 | €42.00 | €14616.00
 | Ancillaries to Blockwork
 | Form cavity between block outer leaf and timberframe inner leaf, include for fitting suitable wall ties (supplied by TF company), capable of supporting and restraining
3 | ^^^130 mm wide. |  | 348.00 | m2 | €6.50 | €2262.00
4 | ^^^Close cavity at reveals of openings with insulated cavity closer - supplied by TF company |  | 143.00 | m | €5.00 | €715.00
5 | ^^^Close cavity at eaves of openings with insulated cavity closer - supplied by TF company |  | 117.00 | m | €5.00 | €585.00
 | Sundries
 | Insulated Damp Proof Courses
 | "Ruberclose Insulated" or equal approved dpc bedded in cement mortar
6 | ^^^475 mm girth; cavity tray DPC |  | 41.00 | m | €8.50 | €348.50
 | Sundries
7 | ^^^Cavity Trays |  | 118.00 | nr | €19.00 | €2242.00
8 | ^^^Catchment Trays |  | 10.00 | nr | €24.00 | €240.00
9 | ^^^Ridge Trays |  | 1.00 | nr | €24.00 | €24.00
EXTERNAL WALLS |  | Total : | €21858.50
Trade : | 4 | STAIRS
 | STAIRS
 | Internal Stairs
1 | ^^^PC Sum of Ç15,000 for open tring steel stairs clad with timber threads and finished with framelss glass balustrade |  | 1.00 | Item | €15000.00 | €15000.00
STAIRS |  | Total : | €15000.00
Trade : | 5 | INTERNAL JOINERY
 | INTERNAL JOINERY
 | Internal Doors
 | Deanta shaker style interal doors, primed finish, including red deal frame and ironmongery - Contractor to allow for all labours and materials required for installation
1 | ^^^Size: 0.90 x 2.10m (PC Sum of Ç250 for supply of door including ironmongery) |  | 11.00 | nr | €565.00 | €6215.00
2 | ^^^Size: 0.70 x 2.10m (Service door) |  | 2.00 | nr | €510.00 | €1020.00
3 | ^^^Size: 0.90 x 2.10m (Sliding Door) |  | 2.00 | nr | €950.00 | €1900.00
4 | ^^^Size: 1.20 x 2.10m (Double Sliding Door) |  | 1.00 | nr | €1800.00 | €1800.00
5 | ^^^Size: 4.50 x 2.10m (Sliding Door) - PROVISIONAL |  | 1.00 | nr | €7000.00 | €7000.00
6 | ^^^Size: 3.80 x 2.10m (Sliding Doors - Mezz) - PROVISIONAL |  | 1.00 | nr | €4000.00 | €4000.00
7 |  |  |  | noid
 | Window Boards
 | 15mm thick primed and sealed moisture resistant MDF with treated cut ends fixed to softwood grounds with heads punched home and filled ready for decoration
8 | ^^^Window boards, 225mm wide x 15mm thick, rounded edges, fixing to blockwork at 300mm centres; size: |  | 29.00 | m | €32.00 | €928.00
9 | ^^^^^Extra over for 15mm thick bosig phonotherm |  | 29.00 | m | €38.83 | €1126.07
10 |  |  |  | noid
 | Skirting
 | Primed and Molded MDF skirting
11 | ^^^125 x 25mm; neatly mitred at ends, angles and intersections. |  | 295.00 | m | €12.00 | €3540.00
INTERNAL JOINERY |  | Total : | €27529.07
Trade : | 6 | WINDOWS AND EXTERNAL DOORS
 | WINDOWS AND DOORS
1 | ^^^PC Sum of Ç45,839.54 for installation of NorDan Aluclad windows and doors - Including Cills |  | 1.00 | Item | €45839.54 | €45839.54
2 | ^^^PC Sum of Ç3,000 for Blackout Blinds |  | 1.00 | Item | €3000.00 | €3000.00
 | Sundries
3 | ^^^Allow for mastic seal to perimeter of the windows and doors |  | 1.00 | Item | €925.00 | €925.00
WINDOWS AND EXTERNAL DOORS |  | Total : | €49764.54
Trade : | 7 | ROOFLIGHTS
 | ROOFLIGHTS
 | Velux or similar approved
1 | ^^^Rooflights, 780 x 1,400 GGU MK08 008230, White polyurethane, centre pivot |  | 10.00 | nr | €2501.20 | €25012.00
2 | ^^^^^Extra over for blind |  | 5.00 | nr | €218.40 | €1092.00
3 | ^^^^^Extra over for shutter |  | 4.00 | nr | €590.10 | €2360.40
4 | ^^^Rooflights, 1,140 x 1,180 GGU MK08 008230, White polyurethane, centre pivot |  | 1.00 | nr | €2885.50 | €2885.50
5 | ^^^^^Extra over for shutter |  | 1.00 | nr | €648.90 | €648.90
ROOFLIGHTS |  | Total : | €31998.80
Trade : | 8 | WALL FINISHES EXTERNALLY
 | WALL FINISHES EXTERNALLY
 | In-Situ Finishes
 | K-Rend or similar synthetic render applied to blockwork external walls
1 | ^^^Exceeding 300 mm wide. |  | 298.00 | m2 | €84.70 | €25240.60
2 | ^^^Not exceeding 150mm wide: reveals. |  | 127.00 | m | €38.50 | €4889.50
3 | ^^^^^Extra over for 15mm thick bosig phonotherm to window/door heads |  | 39.00 | m | €38.83 | €1514.37
4 | ^^^Not exceeding 150mm wide: plinth |  | 101.00 | m | €38.50 | €3888.50
5 | ^^^Plaster band detail at eaves and verges |  | 89.00 | m | €38.50 | €3426.50
 | Sundries
 | Approved stainless steel expanded metal lathing and beading, fixed in accordance with the manufacturers instructions
6 | ^^^Angle Bead |  | 162.00 | m | €8.80 | €1425.60
7 | ^^^Stop bead |  | 156.00 | m | €8.80 | €1372.80
8 | ^^^Belcast bead |  | 101.00 | m | €8.80 | €888.80
 | Timber Cladding
 | Charred larch cladding on battens and counter battens including breathable membrane
9 | ^^^Exceeding 300 mm wide. |  | 50.00 | m2 | €150.50 | €7525.00
10 | ^^^Reveals |  | 16.00 | m | €48.00 | €768.00
11 | ^^^^^Extra over for 15mm thick bosig phonotherm to window/door heads |  | 3.00 | m | €38.83 | €116.49
12 | ^^^Base |  | 16.00 | m | €7.00 | €112.00
13 | ^^^Head |  | 16.00 | m | €7.00 | €112.00
WALL FINISHES EXTERNALLY |  | Total : | €51280.16
Trade : | 9 | WALL FINISHES INTERNALLY
 | WALL FINISHES INTERNALLY
 | Plasterboard Finishes
 | 15 mm thick plasterboard; joints taped and filled; finish with 3 mm thick Gypsum Pinnacle or equivalent skimcoat plaster; steel trowelled finish ready for decoration
1 | ^^^Exceeding 300mm wide |  | 348.00 | m2 | €36.00 | €12528.00
2 | ^^^Not exceeding 300mm wide: reveals. |  | 127.00 | m | €22.00 | €2794.00
 | 12.5 mm thick plasterboard; joints taped and filled; finish with 3 mm thick Gypsum Pinnacle or equivalent skimcoat plaster; steel trowelled finish ready for decoration
3 | ^^^Exceeding 300mm wide |  | 585.00 | m2 | €34.00 | €19890.00
4 | ^^^Provisional Allowance of 30m2 for timber grounds for services etc. |  | 1.00 | Item | €960.00 | €960.00
 | Metalwork
 | "Expamet" or equivalent p.v.c. coated aluminium beads fixed to solid concrete blockwork with "Hilti" or equivalent steel washered masonry nails, include for working plaster into sides of bead in the following
5 | ^^^Angle bead, |  | 177.00 | m | €8.40 | €1486.80
 | Wall Tiling
 | Wall tiles; 3mm joints; layout in whole units with cut margins and make up pieces as neccessary; fixing with approved adhesive in accordance with manufacturers instructions; grouting joints with approved waterproofing grout (PC Sum of Ç35/m2 for supply o
6 | ^^^Exceeding 300mm wide |  | 114.00 | m2 | €91.75 | €10459.50
 | Deco Stone brick slips fixed to internal walls - Area to be confirmed
7 | ^^^Exceeding 300mm wide |  | 40.00 | m2 | €138.00 | €5520.00
WALL FINISHES INTERNALLY |  | Total : | €53638.30
Trade : | 10 | FLOOR FINISHES
 | FLOOR FINISHES
 | Timber Floors
 | Laminate Timber Flooring; layout in whole units with cut margins and make up pieces as neccessary; fixing with approved adhesive in accordance with manufacturers instructions; (PC Sum of Ç30/m2 for supply of timber flooring and trims. Contractor to allow
1 | ^^^Exceeding 300mm wide |  | 203.00 | m2 | €61.50 | €12484.50
 | Floor Tiling
 | Floor tiles; 3mm joints; layout in whole units with cut margins and make up pieces as neccessary; fixing with approved adhesive in accordance with manufacturers instructions; grouting joints with approved waterproofing grout (PC Sum of Ç35/m2 for supply
2 | ^^^Exceeding 300mm wide |  | 135.00 | m2 | €91.75 | €12386.25
 | Sundries
3 | ^^^Allow for fibreglass tanking to shower areas (Floors and Walls) |  | 39.00 | m2 | €45.00 | €1755.00
FLOOR FINISHES |  | Total : | €26625.75
Trade : | 11 | CEILING FINISHES
 | CEILING FINISHES
 | Plasterboard Finishes
 | 15 mm thick plasterboard; joints taped and filled; finish with 3 mm thick Gypsum Pinnacle or equivalent skimcoat plaster; steel trowelled finish ready for decoration
1 | ^^^Exceeding 300mm wide |  | 440.00 | m2 | €36.00 | €15840.00
2 | ^^^^^Extra over last for moisture board |  | 9.00 | m2 | €2.50 | €22.50
3 | ^^^50mm mineral wool insulation to underside of rafters |  | 266.00 | m2 | €11.38 | €3027.08
4 | ^^^^^Extra over for batten to from service void |  | 266.00 | m2 | €8.00 | €2128.00
 | MF Ceiling finished with 12.5 mm thick plasterboard; joints taped and filled; finish with 3 mm thick Gypsum Pinnacle or equivalent skimcoat plaster; steel trowelled finish ready for decoration
5 | ^^^Exceeding 300mm wide |  | 174.00 | m2 | €61.00 | €10614.00
6 | ^^^^^Extra over last for moisture board |  | 22.00 | m2 | €2.50 | €55.00
CEILING FINISHES |  | Total : | €31686.58
Trade : | 12 | ROOF FINISHES
 | ROOF FINISHES
 | Pitched Roof Coverings
 | Tergal Rivendale Slate 600 x 300mm slates fixed with 100mm headlap and 250mm gauge, each slate fixed with 2No. 11SWG copper nails to and including 47 x 22mm vac-vac treated timber battens through and including Underlay fixed to timber rafters at 400mm cen
1 | ^^^Coverings; sloping < 45 degrees; > 300 mm wide. |  | 239.00 | m2 | €63.79 | €15245.81
 | Eaves;
2 | ^^^Double eaves course. |  | 53.00 | m | €11.00 | €583.00
 | Verge Detail
3 | ^^^Verge Detail |  | 34.00 | m | €12.50 | €425.00
 | Valleys
4 | ^^^Labours in forming valleys |  | 12.00 | m | €25.00 | €300.00
 | Ridges
 | Ridge cap; each one drilled and screwed to and including extra wide batten; thinly bedded and pointed in pigmented cement and sand mortar (1:3)
5 | ^^^Ridge; horizontal. |  | 30.00 | m | €28.00 | €840.00
 | Flat Roof Finishes
 | Warm roof single ply membrane system laid 100mm Kingspan Thermaroof TR27 insulation on vapour control layer on timber subbase
6 | ^^^Exceeding 300mm wide |  | 26.00 | m2 | €145.00 | €3770.00
7 | ^^^^^Extra over for area of roof where terrace is located |  | 13.00 | m2 | €35.00 | €455.00
8 | ^^^Upstand to parapets |  | 40.00 | m | €50.00 | €2000.00
9 | ^^^Form rainwater outlets |  | 3.00 | nr | €150.00 | €450.00
10 | ^^^PPC capping |  | 23.00 | m | €125.00 | €2875.00
 | Code 5 lead flashings; patination oil
 | Flexible Sheet Metal Coverings
 | Code No. 5 milled sheet lead to B.S.1178 having a thickness of 2.24 mm; lapped 150 mm at all joints ( measured nett ) fixed with and include for lead clips, tacks and wedges where necessary; evenly apply two coats of "Cookson" or equivalent patination
11 | ^^^Lead flashing to wall abutments |  | 42.00 | m | €65.00 | €2730.00
12 | ^^^Valleys |  | 12.00 | m | €65.00 | €780.00
 | Fascia
 | "Hardwood" or equivalent fascia lining boards fixed to deal grounds;
13 | ^^^Fascia |  | 55.00 | m | €35.00 | €1925.00
14 | ^^^Over Fasica Continuous ventilation strip. |  | 55.00 | m | €3.00 | €165.00
ROOF FINISHES |  | Total : | €32543.81
Trade : | 13 | DRAINAGE & REFUSE DISPOSAL
 | DRAINAGE & REFUSE DISPOSAL
 | Gutters and Downpipes
 | Powder coated rainwater system, fixed through backing (elsewhere measured) with and including gutter brackets at 800mm maximum centres, leave in a perfectly watertight condition to the satisfaction of the Architect and fixed in strict accordance with th
 | Eaves Gutters; surface fixed; black
1 | ^^^Nominal size 125 x 75 mm |  | 49.00 | m | €66.00 | €3234.00
2 | ^^^Fittings; Nozzle outlet (75mm). |  | 7.00 | nr | €42.00 | €294.00
3 | ^^^Fittings; Stop ends |  | 10.00 | nr | €20.00 | €200.00
4 | ^^^Fittings; Bends |  | 1.00 | nr | €34.00 | €34.00
 | Powder coated Pipes; rainwater downpipes.
5 | ^^^Nominal size 75 mm x 75 mm. |  | 45.00 | m | €60.00 | €2700.00
6 | ^^^Fittings; Swan neck; 300 mm offset. |  | 10.00 | nr | €42.00 | €420.00
7 | ^^^Fittings; Splash shoe. |  | 10.00 | nr | €42.00 | €420.00
8 | ^^^Fittings; Hoppers |  | 3.00 | nr | €150.00 | €450.00
DRAINAGE & REFUSE DISPOSAL |  | Total : | €7752.00
Trade : | 14 | INTERNAL DECORATION
 | PAINTING AND DECORATING
 | Internal Work
 | Decoration to Timber
 | Knot, prime, stop, grain fill and apply two undercoats and one finishing coat of satin oil paint to
1 | ^^^Window boards not exceeding 300 mm girth |  | 29.00 | m | €4.50 | €130.50
2 | ^^^Skirting not exceeding 200 mm girth |  | 295.00 | m | €4.50 | €1327.50
3 | ^^^Timber door frames and linings exceeding 300mm girth |  | 99.00 | m | €4.50 | €445.50
4 | ^^^Timber architraves |  | 198.00 | m | €4.50 | €891.00
 | Decoration to Walls and Ceilings
 | Thoroughly clean down, brush off loose particles, remove any grease or dirt, prepare and apply one coat thinned and two full coats "Dulux" or equivalent vinyl matt emulsion in selected colours (maximum of 2 per room) on
5 | ^^^Plastered walls |  | 684.00 | m2 | €10.00 | €6840.00
6 | ^^^Plastered reveals; not exceeding 300 mm wide. |  | 127.00 | m | €5.00 | €635.00
7 | ^^^Plastered ceilings generally. |  | 345.00 | m2 | €11.00 | €3795.00
INTERNAL DECORATION |  | Total : | €14064.50
Trade : | 15 | BUILT IN FITTINGS
 | BUILT IN FITTINGS
 | Kitchen & Utility
1 | ^^^PC Sum of Ç8,000 for a fitted kitchen |  | 1.00 | Item | €8000.00 | €8000.00
 | Wardrobes
2 | ^^^PC Sum of Ç1,500 for fitted wardrobes |  | 1.00 | Item | €1500.00 | €1500.00
 | Miscellaneous
3 | ^^^PC Sum of Ç1,000 for fitted cloaks section, seating, benches etc. |  | 1.00 | Item | €1000.00 | €1000.00
BUILT IN FITTINGS |  | Total : | €10500.00
Trade : | 16 | MECHANICAL INSTALLATIONS
 | MECHANICAL INSTALLATION
 | Heating and Plumbing Installation
1 | ^^^PC Sum of Ç14,000 for Plumbing Installations complete - General plumbing, supply of tanking and fitting of sanitary ware |  | 1.00 | Item | €14000.00 | €14000.00
 | Heat Recovery
2 | ^^^PC Sum of Ç9,000 for Heat Recovery Installations complete |  | 1.00 | Item | €9000.00 | €9000.00
 | Sanitary Ware
3 | ^^^PC Sum of Ç3,000 for supply of sanitary ware |  | 1.00 | Item | €3000.00 | €3000.00
 | Sprinkler System
4 | ^^^PC Sum of Ç10,595 for supply and installation of sprinkler system |  | 1.00 | Item | €10595.00 | €10595.00
 | Builders Works
5 | ^^^Builders work associated with the heating and plumbing installations |  | 1.00 | Item | €1400.00 | €1400.00
MECHANICAL INSTALLATIONS |  | Total : | €37995.00
Trade : | 17 | ELECTRICAL INSTALLATIONS
 | ELECTRICAL INSTALLATION
 | Electrical Installations
1 | ^^^PC Sum of Ç25,000 for electrical installation complete be RECI electrician - Assuming all wiring will be completed by the electrician, all internal wiring to be standard including PVC fixtures and fittings (Client to complete any additional wiring post |  | 1.00 | Item | €25000.00 | €25000.00
 | Security
2 | ^^^PC Sum of Ç5,000 for first and second fix security installation |  | 1.00 | Item | €5000.00 | €5000.00
 | External Lighting
3 | ^^^PC Sum of Ç5,000 for installation of external lighting |  | 1.00 | Item | €5000.00 | €5000.00
 | Solar/PV
4 | ^^^PC Sum Ç3,500 for fitting of PV Panel system - Client has supplied and fitted some of these items on site already |  | 1.00 | Item | €3500.00 | €3500.00
 | Builders Works
5 | ^^^Builders work associated with the electrical installations |  | 1.00 | Item | €840.00 | €840.00
ELECTRICAL INSTALLATIONS |  | Total : | €39340.00
Trade : | 18 | SITE PREPARATION (PROVISIONAL)
 | SITE PREPARATION
1 | ^^^Provisional Sum of Ç9,000 for clearing the site and disposing of material as necessary off site |  | 1.00 | Item | €9000.00 | €9000.00
SITE PREPARATION (PROVISIONAL) |  | Total : | €9000.00
Trade : | 19 | SITE STRUCTURES
 | SITE STRUCTURES
 | Entrance Wall
1 | ^^^Allow for constructing 1.00m high blockwork walls with 215mm blockwork and stone finish |  | 41.00 | m | €444.25 | €18214.25
2 | ^^^^^Extra over for piers |  | 8.00 | nr | €250.00 | €2000.00
3 | ^^^Provisional Sum of Ç6,000 for automated sliding entrance gate |  | 1.00 | Item | €6000.00 | €6000.00
4 | ^^^Allow for new pedestrian entrance gates |  | 1.00 | Item | €750.00 | €750.00
5 |  |  |  | noid
 | Fencing
6 | ^^^1.80m high post and panel fence |  | 40.00 | m | €85.00 | €3400.00
7 |  |  |  | noid
 | Walled Garden
8 | ^^^Allow for constructing 1.00m high blockwork walls with 215mm blockwork and plaster finish both sides |  | 15.00 | m | €413.25 | €6198.75
9 | ^^^^^Extra over for piers |  | 4.00 | nr | €250.00 | €1000.00
10
SITE STRUCTURES |  | Total : | €37563.00
Trade : | 20 | HARDSURFACING
 | DRIVEWAY
 | Filling
 | Hardcore; Structural granular fill T1 or equal approved material in accordance with Engineers' Specification; depositing and compacting in layers 150mm maximum thickness
1 | ^^^150mm thick. |  | 86.00 | m2 |  | €0.00 | EXCL
 | Surface Treatments
2 | ^^^50mm thick limestone blinding |  | 86.00 | m2 | €4.00 | €344.00
 | Tarmacadam
3 | ^^^60mm tarmacadam finish to the driveway |  | 86.00 | m2 | €35.00 | €3010.00
4 |  |  |  | noid
 | PATHS
 | Filling
 | Hardcore; Structural granular fill T1 or equal approved material in accordance with Engineers' Specification; depositing and compacting in layers 150mm maximum thickness
5 | ^^^150mm thick. |  | 228.00 | m2 |  | €0.00 | EXCL
 | Surface Treatments
6 | ^^^50mm thick sand/cement blinding |  | 228.00 | m2 | €8.00 | €1824.00
 | Paving
7 | ^^^30mm thick precast concrete paviour |  | 228.00 | m2 | €91.75 | €20919.00
8 |  |  |  | noid
 | PATHS
 | Filling
 | Hardcore; Structural granular fill T1 or equal approved material in accordance with Engineers' Specification; depositing and compacting in layers 150mm maximum thickness
9 | ^^^150mm thick. |  | 30.00 | m2 |  | €0.00 | EXCL
 | Surface Treatments
10 | ^^^50mm thick limestone blinding |  | 30.00 | m2 | €8.00 | €240.00
 | Gravel
11 | ^^^50mm thick gravel to paths |  | 30.00 | m2 | €20.00 | €600.00
12 |  |  |  | noid
 | PLAY AREA
13 | ^^^Provisional Sum of Ç1,000 for surfacing to the kids play area (Mulch or similar) |  | 1.00 | Item | €1000.00 | €1000.00
HARDSURFACING |  | Total : | €27937.00
Trade : | 21 | SITE SERVICES (Piped & Ducted) (PROVISIONAL)
 | SITE SERVICES (Piped & Ducted)
 | Foul Drainage
 | Excavate trench for and including 100mm UPVC drain pipe, pea gravel bed and surround, backfill with selected excavated material and remove surplus.
1 | ^^^Average depth 1.00m |  | 81.00 | m | €26.00 | €2106.00
2 | ^^^Armstrong junctions |  | 6.00 | nr | €155.00 | €930.00
3 | ^^^Manholes, not exceeding 1.00m deep |  | 1.00 | nr | €950.00 | €950.00
4 | ^^^Gully trap and bends |  | 3.00 | nr | €55.00 | €165.00
5 | ^^^Vent stack |  | 1.00 | Item | €200.00 | €200.00
6 | ^^^Allow for connection to the existing sewer on the site |  | 1.00 | Item | €400.00 | €400.00
 | Surface Drainage
 | Excavate trench for and including 100mm UPVC drain pipe, pea gravel bed and surround, backfill with selected excavated material and remove surplus.
7 | ^^^Average depth 1.00m |  | 154.00 | m | €22.00 | €3388.00
8 | ^^^Armstrong junctions |  | 7.00 | nr | €155.00 | €1085.00
9 | ^^^Gully trap and bends |  | 10.00 | nr | €55.00 | €550.00
10 | ^^^Domestic ACO drains |  | 10.00 | m | €100.00 | €1000.00
11 | ^^^Heavy Duty ACO drains |  | 6.00 | m | €120.00 | €720.00
12 | ^^^French Drains |  | 41.00 | m | €45.00 | €1845.00
13 | ^^^Soakaways |  | 1.00 | nr | €450.00 | €450.00
14 | ^^^Allow for connection to the existing sewer on the site |  | 1.00 | Item | €400.00 | €400.00
15 | ^^^Provisional Sum of Ç5,000 for supply and installation of rainwater harvesting unit |  | 1.00 | Item | €5000.00 | €5000.00
16 | ^^^Provisional Sum of Ç2,000 for supply and installation of reed bed (9m2) |  | 1.00 | Item | €2000.00 | €2000.00
SITE SERVICES (Piped & Ducted) (PROVISIONAL) |  | Total : | €21189.00
Trade : | 22 | WATER SUPPLY (PROVISIONAL)
 | WATER SUPPLY
 | Feed to dwelling
1 | ^^^Watermain supply from mains |  | 30.00 | m | €25.00 | €750.00
2 | ^^^Allow for connection to mains water |  | 1.00 | Item | €700.00 | €700.00
WATER SUPPLY (PROVISIONAL) |  | Total : | €1450.00
Trade : | 23 | SITE SERVICES (Mainly Electrical) (PROVISIONAL)
 | SITE SERVICES (MAINLY ELECTRICAL)
1 | ^^^Main services have been installed on site - As noted by client |  |  | Note
2 | ^^^Allow for short runs of ducts (110mm + 50mm & 50mm + 50mm) - Max 15m of trench |  | 1.00 | Item | €450.00 | €450.00
SITE SERVICES (Mainly Electrical) (PROVISIONAL) |  | Total : | €450.00
Trade : | 24 | GREENHOUSE
 | GREENHOUSE/POOL ROOM
1 | ^^^Allow for insulated foundations to the green house glazed walls - As per Long Life Structures |  | 1.00 | Item | €23240.90 | €23240.90
2 | ^^^^200mm high wall to support green house - quinnlite blocks |  | 1.00 | Item | €1683.81 | €1683.81
3 | ^^^PC Sum of Ç34,800 ex VAT for nthe green house glazing |  | 1.00 | Item | €34800.00 | €34800.00
4 | ^^^Rainwater tank to the greenhouse |  | 1.00 | Item | €2000.00 | €2000.00
GREENHOUSE |  | Total : | €61724.71
Trade : | 25 | GARAGE
 | GARAGE
1 | ^^^Allow for masonry built garage including standard strip foundation, insulated floor slab, uninsulated 150mm wide cavity walls, burnt larch cladding externally, pointed blockwork internally including warm roof flat roof system |  | 1.00 | Item | €70000.00 | €70000.00
GARAGE |  | Total : | €70000.00
Trade : | 26 | PRELIMINARIES
 | PRELIMINARIES
1 | Site Supervision |  | 1.00 | Item |  | €0.00 | EXCL
2 | Insurances |  | 1.00 | Item | €2200.00 | €2200.00
3 | Scaffolding |  | 1.00 | Item | €13000.00 | €13000.00
4 | Health & Safety |  | 1.00 | Item |  | €0.00 | EXCL
5 | General Plant |  | 1.00 | Item |  | €0.00 | EXCL
6 | Lighting & Power |  | 1.00 | Item |  | €0.00 | INCL
7 | Water Supply (use of supply on site) |  | 1.00 | Item |  | €0.00 | INCL
8 | Cleaning on Completion |  | 1.00 | Item |  | €0.00 | EXCL
9 | Waste Disposal & Skips |  | 10.00 | nr | €450.00 | €4500.00
PRELIMINARIES |  | Total : | €19700.00
Trade : | 27 | NOTES & EXCLUSIONS
 | Notes
1 | ^^^Insulated raft has been included in the budget - As per Long life Structure quote |  |  | Note
2 | ^^^Timberframe priced by Long Life Structure - The systrem used is the Eco 220 with 80mm Gutex |  |  | Note
3 | ^^^Windows and doors are included as per NorDan quotation including cills |  |  | Note
4 | ^^^All rates valid as of 14/06/2024 |  |  | Note
5 | ^^^We would advise that rate are likely to increase in the coming months |  |  | Note
6 | ^^^Allowance has been made for fitting the PV system on to the building - Client has supplied the required equipment already |  |  | Note
7 | ^^^PC Sum has been included for all wiring and electrics based on having an electrician do the full install. |  |  | Note
8 | ^^^The rates used are builders rates - If the client goes direct labour these rates may differ. |  |  | Note
9 | ^^^No calculation has been made for varying VAT rates for direct labour - all VAT is charged at 13.5% |  |  | Note
10 | ^^^All airtightness to be completed by LLS |  |  | Note
11 | ^^^All hardcore has been completed to date. No allowance has been made for additional hardcore |  |  | Note
12 | ^^^We have included for 10 kips for general waste, scaffolding and insurances only in the preliminaries |  |  | Note
13 |  |  |  | noid
 | Exclusions
14 | ^^^Soft Spots |  |  | Note
15 | ^^^Rock Excavation |  |  | Note
16 | ^^^Road opening licences and connection fees |  |  | Note
17 | ^^^County Council & Public utility fees eg. Contributions, ESB connection, Eircom connection etc. |  |  | Note
18 | ^^^Professional fees |  |  | Note
19 | ^^^Planning fees/contributions |  |  | Note
20 | ^^^Site Lighting, External Lighting |  |  | Note
21 | ^^^Soft Landscaping |  |  | Note
22 | ^^^Appliances and furniture |  |  | Note
23 | ^^^Supervision, Health and Safety, Plant, Cleaning etc. - Client to review and account for seperately |  |  | Note
NOTES & EXCLUSIONS |  | Total :
Trade : | 28 | Subtotal Ex VAT @ 13.5%
Subtotal Ex VAT @ 13.5% |  | Total : | €1064812.42
Trade : | 29 | VAT @ 13.5%
1
VAT @ 13.5% |  | Total : | €143749.68
Trade : | 30 | Subtotal Including VAT
1
Total Including VAT |  | Total : | €1208562.10
Trade : | 31 | CLIENT DIRECT WORKS
 | CLIENT DIRECT WORKS
1 | ^^^Fronius Symo GEN24 |  | 1.00 | Item |  | €0.00 | EXCL
2 | ^^^Lithium Battery |  | 1.00 | Item |  | €0.00 | EXCL
3 | ^^^Fronius Ohmiplot |  | 1.00 | Item |  | €0.00 | EXCL
4 | ^^^EV Charger |  | 1.00 | Item | €1000.00 | €1000.00
5 | ^^^Thermal Store - Linszter |  | 1.00 | Item | €4536.00 | €4536.00
6 | ^^^Sauna - costs taken from house handbook + 15% |  | 1.00 | Item | €1864.00 | €1864.00
7 | ^^^Roof Harvester Rainwater - To be potentially omitted |  | 1.00 | Item | €5000.00 | €5000.00
8 | ^^^Reverse Osmosis |  | 1.00 | Item | €302.00 | €302.00
9 | ^^^Pool - Based on updated notes from the client |  | 1.00 | Item | €60000.00 | €60000.00
10 | ^^^Greenhouse grow lighting |  | 1.00 | Item | €4000.00 | €4000.00
11 | ^^^PC Sum of Ç10,000 for custom fireplace and wood burning stove |  | 1.00 | Item | €10000.00 | €10000.00
CLIENT DIRECT WORKS |  | Total Including VAT: | €86702.00

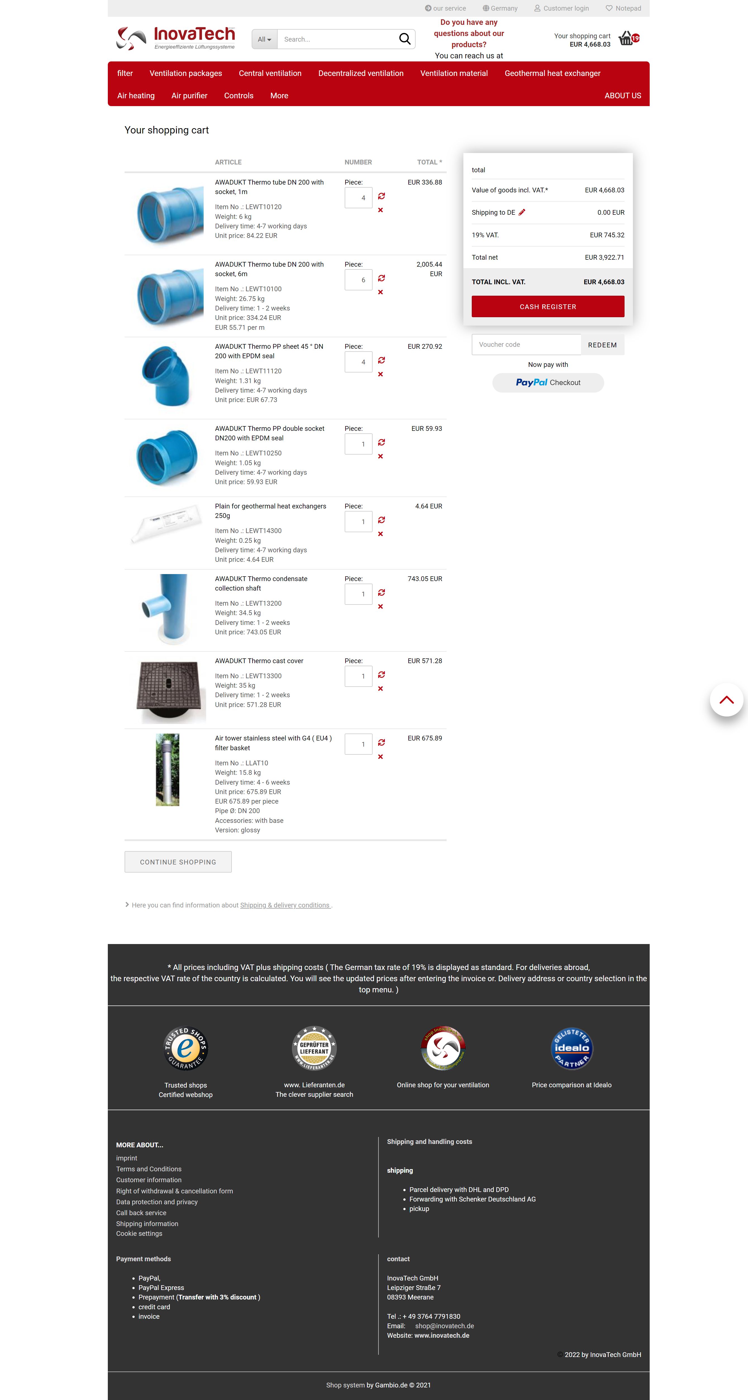
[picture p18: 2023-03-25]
designs/20230313 Earth Tube Parts cost shop.inovatech.de_de_shopping_cart.php.png

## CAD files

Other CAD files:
quotes/20240131_LongLifeStructures/Timber Frame ECO220 Cad Detail.dwg
surveys_maps_docs/20230508 23-05-1048 Topographical Survey at 29-30 Ard Na Si, Banteer.dwg
surveys_maps_docs/20210428 21-04-748 Topographical Survey at 29-30 Ard Na Si, Banteer.dwg

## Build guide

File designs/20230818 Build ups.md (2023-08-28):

1. The sloping roof uses 62.5mm insulated plasterboard which is 50mm of PIR bonded onto 12.5mm of gypsum, usually from Unilin. There is a 22 mm service cavity on the sloping roof. Behind that is the rafters filled 220 mm deep with mineral wool (Metac 034).

2. The flat roof uses 15mm non-insulated plasterboard (Gyproc), then there is a 22 mm service cavity. The rafters are 220mm filled with 220mm deep Metac 034 mineral wool. Lying on top of the rafters is 18mm OSB3, 150mm thick Unilin FR/TP PIR with upper 18mm OSB3 underneath outer zinc panels/EPDM sheet.

3. The outer walls use 15mm non-insulated plasterboard (Gyproc), then there is a 35 mm service cavity, then the 50mm of PIR board as a thermal break (Unilin), then 140mm studs with 135mm thick Kingspan K3 phenolic within them.

4. The floor is Supergrund or KORE depending on whoever can get it done first. U-value is 0.10.

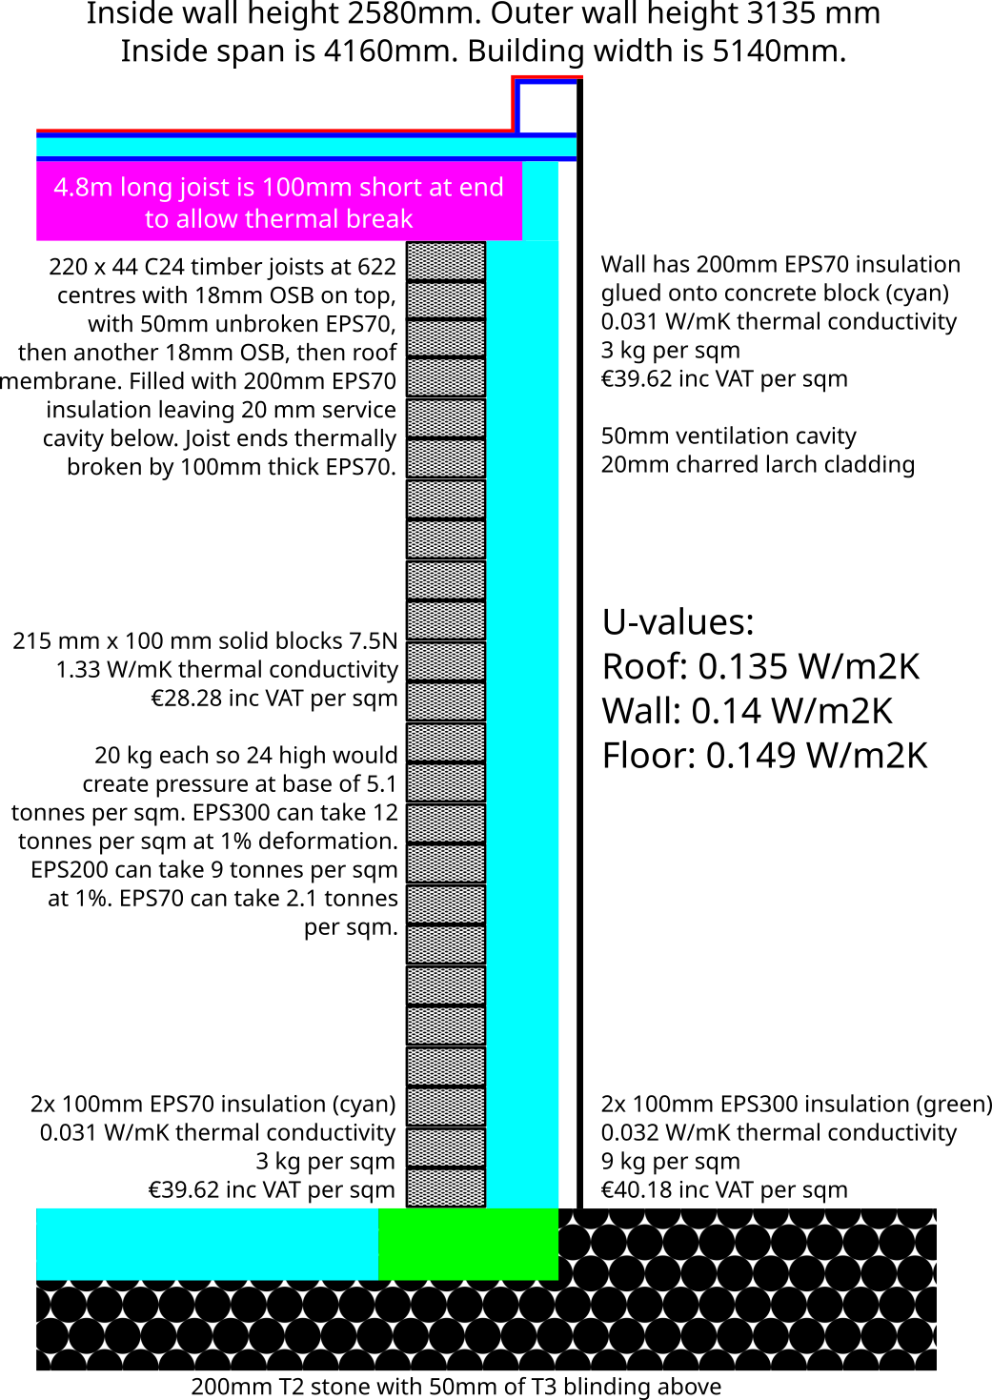
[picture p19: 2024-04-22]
designs/20240412_outhouse_buildup_idea3.png

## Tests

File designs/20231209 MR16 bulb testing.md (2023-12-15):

1. 3000K very cheap Chinese bulb @ 100%: 72.3 C

2. 3000K very cheap Chinese bulb @ 50%: 60.5 C

3. 3000K very cheap Chinese bulb @ 25%: 46.9 C

4. 3500K expensive Satco CRI90 bulb @ 100%: 49.8 C

5. 3500K expensive Satco CRI90 bulb @ 50%: 46.5 C

6. 3500K cheaper Satco CRI80 bulb @ 100%: 66.3 C

7. 4000K very cheap Chinese bulb @ 100%: 73.2 C

8. 4000K very cheap Chinese bulb @ 50%: 44.1 C

9. 4000K very cheap Chinese bulb @ 25%: 33.8 C

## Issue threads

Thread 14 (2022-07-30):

Install earth rod personally, as groundworks people refuse to touch anything potentially electrical. Make sure levels are correct.

ned14, 2022-07-30:

Closed 2022-12-09.

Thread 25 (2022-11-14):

Route conduit along western wall carrying three phase mains, two network cable, 16-25m2 earth cable, and 60v DC cable

ned14, 2022-11-14:

ned14, 2022-11-26:
From https://www.energy-solutions.co.uk/technical-information and https://www.spwales.com/cable-size-current-rating-chart

Sizing notes for the far end:

- Far end mains distribution box has 1x 16a three phase. 1.5 mm2 30 meter roll would do it, though 2.5 mm2 feels safer if one were to use the single phase sockets at the same time. Maybe I am overthinking it.
- 60v DC if 6 mm2 would carry 2.4kW which is probably overkill. 4 mm2 would carry 1.8kW. 2.5 mm2 would carry 1.3kW. I have 90m of solid core 2.5 mm2 already.
- Two network cables, one for the IoT network which has no access to anything, the other for the far end wifi unit.

Sizing notes for the middle:

- In addition to the far end cables, also need a 16-25m2 earth cable (90-120 amps), and 2x three phase for the house. Assuming a maximum possible domestic three phase connection (29 kVA) which has a 80 amp fuse (according to the ESB), that is a max of 27 amps per cable in the three phase cable, which is 4 mm2. I note that industrial 32 amp five pin plug cables are 4 mm2, though I think 6 mm2 would actually be more appropriate for > 30 amps.
- The inverter can supply a max of 15 amps per phase in backup mode, so house backup three phase can be 1.5 mm2. There is a strong argument that this three phase would be converted into a 10 kW single phase in the house using a phase converter after the three phase AC to 60v DC converter. The non-backup three phase is mainly expected to heat the thermal store, which is 9 kW, so the other three phase can also be 1.5 mm2. I note that the inverter's docs say that 4 mm2 is the smallest for the backup, and 6 mm2 is the smallest for mains.
- Two fibre optic cables need to run from the middle to the house.
- Two 50m network cables need to run from the middle to the house (IoT 100Mbps network)
- At least 6 mm2 needed for the 60v DC (2.4 kW), possibly 10 mm2 to prevent voltage droop (3.6 kW)
- Solar panel string cables, likely 4x 1.5 mm2 as these are high voltage. I note that the inverter's docs say 4 mm2 is the minimum.

Sizing notes for the near:

- 32a three phase socket is intended for EV charging, with potentially 29 kW coming from mains and 10 kW coming from the inverter which implies 32.5 amps. I think you definitely need 6 mm2 three phase cabling here to the near mains distribution box.
- I'm guessing mains would enter the power meter, go via an AC isolator, and then go to the inverter, the near side three phase distribution, and to the house.
- The inverter then emits a separate backup three phase, with the backup latched onto mains unless mains power drops out.

Diameters:
- 1.5 mm2 four wire is 1.2 cm diameter
- 2.5 mm2 four wire is 1.4 cm diameter
- 4 mm2 four wire is 1.5 cm diameter
- 6 mm2 four wire is 1.7 cm diameter

- 1.5 mm2 five wire is 1.43 cm diameter
- 2.5 mm2 five wire is 1.61 cm diameter
- 4 mm2 five wire is 1.78 cm diameter
- 6 mm2 five wire is 2.0 cm diameter

ned14, 2023-07-16:
Finally got local electrical earth connected. This enables inverter testing.

ned14, 2023-07-17:
Wiring + conduit has been routed to garden shed, where 57v DC power supply shall be eventually located. I haven't yet pulled the 16mm2 57v DC cable to the far distribution box despite the conduit being present, this is because I hate cable pulling with an unusual degree. The conduit is there, it can be pulled when I can't avoid it any longer. I am still marking this issue as closed, as everything I absolutely need now has been done.

Closed 2023-07-17.

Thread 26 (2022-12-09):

Whilst filling in the electrical earth holes, conduct a jam jar soil test

ned14, 2022-12-09:

ned14, 2022-12-09:
For the subsoil jar from about a half metre under the ground:

- Total height of settled material: 56 mm, maybe minus 2mm for glass = 54 mm
- Height of clay layer: 2 mm (3.7%)
- Height of fine silt layer: 23 mm (42.6%)
- Height of course silt layer: 29 mm (53.7%)

For the topsoil jar:

- Total height of settled material: 88 mm, maybe minus 2mm for glass = 86 mm
- Height of clay layer: 2.5 mm (2.9%)
- Height of fine silt layer: 83 mm (96.5%)

Closed 2022-12-09.

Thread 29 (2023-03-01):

Order Awadukt Thermo ground air heat exchanger pipes

ned14, 2023-03-01:

ned14, 2023-06-05:
No longer being fitted, so closing.

Closed 2023-06-05.

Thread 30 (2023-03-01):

Install into future house foundations service pipes and ground air heat exchanger

ned14, 2023-03-01:

ned14, 2023-06-05:
Likely no longer needed as we are no longer implementing a GAHE.

Closed 2023-06-05.

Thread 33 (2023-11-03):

DC, ethernet and fiber routing

ned14, 2023-11-03:
M&E have done ventilation routing.

We have a map of AC sockets and lights.

What remains is to do the routing of DC, ethernet and fiber with correct sizing.

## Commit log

2022-07-27 Materials delivered
    #2
2022-07-28 Add more historical resources
    [20210428 21-04-748 Topographical Survey at 29-30 Ard Na Si, Banteer.dwg, Banteer Irradiation.xlsx]
2022-09-12 7kW of three phase AC to 60v DC power converters have finally arrived from China.
    #8
2022-09-12 Initial groundworks begin #5
2022-09-14 Photos from initial groundworks complete. There is still a fair bit of stuff to do, but this is the lion's share done.
    Closed #1 #5
2022-09-19 Purchased the shipping container for €7k inc VAT delivered #11
2022-10-13 Towable cart purchased and assembled and now ready to move heavy things around the site. Very long overdue!
2022-10-13 Solar powered flood lighting and building number installed. Closes #22.
2022-10-13 Build quote received from EcoTechHomes for €609k inc VAT.
2022-11-01 Earth rods are into ground, but not yet connected. Awaiting rain waters to recede before completing. #14
2022-12-05 2x 50m single mode fibre optic cables and 4x 2.5Gbps single mode fibre SFP transceivers received. Price was surprisingly good, 136 euro ex VAT inc delivery. Same bought locally would be around a gran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
2022-12-05 Was up until 4am assembling the shipping container automation board. Still awaits a 12v to 24v boost converter, a 5v boost converter, and a tilt and motion sensor. And the writing and debugging of th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
2022-12-09 Electrical earth holes are filled in, which closes #14
2022-12-09 Current progress installing conduit and services boxes #25
2023-01-11 Add build quote from Advanced Housing Systems
    Add notes on quotes comparing Ecotech and AHS quotes
2023-01-14 Installation of electrical conduit on western wall is finally complete. Next comes putting wires into that conduit. #25
2023-01-14 Finished assembling and installing the firmware for the broadband internet board. This little board has a 4G modem, Wifi 6, gigabit LAN and 2.5G WAN and SFP cages. Into the SFP cages I have installed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
2023-01-17 Shipping container custom computer has all components present and mounted. Still need to wire them all up, and write and debug its firmware. #21
2023-01-24 Added notes on PWM LED strip dimming
2023-02-02 Completed lighting within the shipping container. Double row 5 meter LED strip outputting (claimed) 12,000 lumen consumes 113 watts including 24v DC converter. Far end 1.5 meter LED tube outputting (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
2023-02-14 Add quote from Timber Frame Ireland.
2023-02-21 Completed wiring in three phase from far end services box to middle services box #25
2023-03-01 All shelving erected and roped onto side of container with 25 cm rear gap suitable for holding 8x 6m long 20 cm pipes for the Awadukt Thermo ground air heat exchanger. Closes #28
2023-03-14 Add neighbour boundary wall plans and ground air heat exchanger plans
2023-03-25 Add design docs and costings for Earth Tube and its retaining walls.
2023-04-15 Add notes on earth tube alternative implementation ideas given the cost to get the Rehau pipes over from Germany.
2023-04-15 Add panorama shot of how the empty site currently looks as of 1st April 2023.
2023-05-04 Add datasheets for other candidate solar panels, solar inverter, battery storage.
2023-05-05 Add build up diagrams for ECO 220 timber frame
2023-06-03 New up to date survey
    [20230508 23-05-1048 Topographical Survey at 29-30 Ard Na Si, Banteer.dwg]
2023-06-05 Entire of the second day of this long weekend went on installing all remaining bottom row of blocks of neighbour boundary wall. My wife did most of the levelling and tamping of the subsoil, followed 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
2023-07-17 Add photos of newly added conduit + wiring into garden shed.
2023-09-04 Stills from western wall cameras
2023-12-08 Add first stage M&E schematics with errata.
    Add first stage lighting design.
2023-12-08 Add DC wiring
2023-12-15 Quote for Mist Suppression System.
    Updated Pool greenhouse design.
    Updated detailed electrical schematics.
2023-12-15 Picture of innards and manual for DC PWM dimmer light switches.
2023-12-15 Picture of CAT6 ethernet cable box just arrived.
2024-01-21 Finally completed detailed wiring schematics for all rooms in the house
2024-01-21 Add pictures of MR16 bulb and LED strip testing
2024-02-24 Add aerial drone photos of site.
    Add quote from Long Life Structures.
    Add design sketches for initial groundworks mk II.
    [Timber Frame ECO220 Cad Detail.dwg]
2024-09-29 Add six months worth of designs, quotes and tech docs
    [17127 - Ard Na Si, Banteer, Co. Cork - KSQS budget estimate 14.06.2024.xls, Agreed Cill Schedule Template.xlsx, extract.ods]
